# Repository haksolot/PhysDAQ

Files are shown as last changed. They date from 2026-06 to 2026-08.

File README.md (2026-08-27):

<p align="center">
  <picture>
    <source media="(prefers-color-scheme: dark)" srcset="assets/physdaq-dark.svg">
    PhysDAQ
  </picture>
</p>

<h1 align="center">PhysDAQ</h1>

<p align="center">
  <strong>Wearable multi-point pulse and motion recording, for research.</strong><br>
  Place the sensors, press record, get clean CSV. No wiring and no code.
</p>

<p align="center">
  
  
  
</p>

<p align="center">
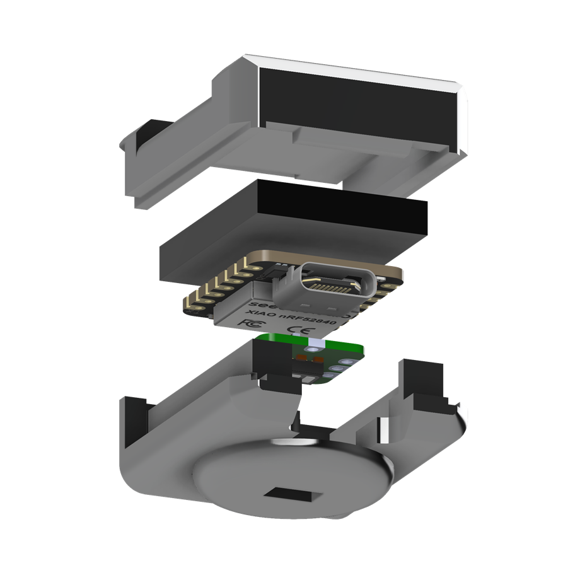
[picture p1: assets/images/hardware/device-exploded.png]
PhysDAQ sensor — exploded view
  
</p>
<p align="center"><sub><i>PhysDAQ sensor node — exploded view showing the XIAO nRF52840, MAX30102 pulse oximeter, LiPo battery and 3D-printed enclosure.</i></sub></p>

---

## Quick start

1. **Install the desktop app.** Download it from the
   [Releases page](https://github.com/haksolot/PhysDAQ/releases) — `.exe` for
   Windows, `.dmg` for Mac, `.AppImage` or `.deb` for Linux. The downloads are
   unsigned, so your system will warn you once; the
   [User Guide](docs/user-guide.md#installing-the-app) says what to click.
2. **Connect a sensor.** Plug it into a USB port, or pair it over Bluetooth from
   the app. The app finds it either way — nothing to configure.
3. **Name your session and press Record.** Every connected sensor is recorded at
   once, and you get one spreadsheet-ready CSV file per sensor in
   `Documents/PhysDAQ_Sessions/`.

Step by step, including where to place a sensor on the body and how to read the
live view: **[User Guide](docs/user-guide.md)**.

---

## Overview

<table>
<tr>
<td width="50%" valign="top">

### Hardware

A compact, battery-powered sensor node that clips to the body. Each unit combines a 6-axis IMU and a clinical-grade pulse oximeter in a 3D-printed enclosure.

<p align="center">
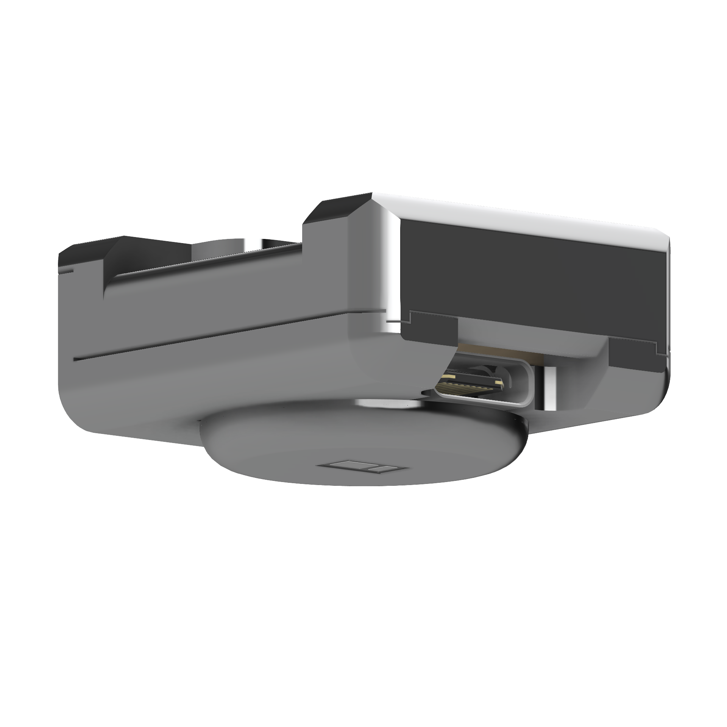
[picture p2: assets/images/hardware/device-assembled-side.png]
Assembled PhysDAQ sensor
  
</p>

</td>
<td width="50%" valign="top">

### Desktop App

A cross-platform acquisition interface that discovers sensors over USB or BLE, displays live signals, and exports timestamped CSVs.

<p align="center">
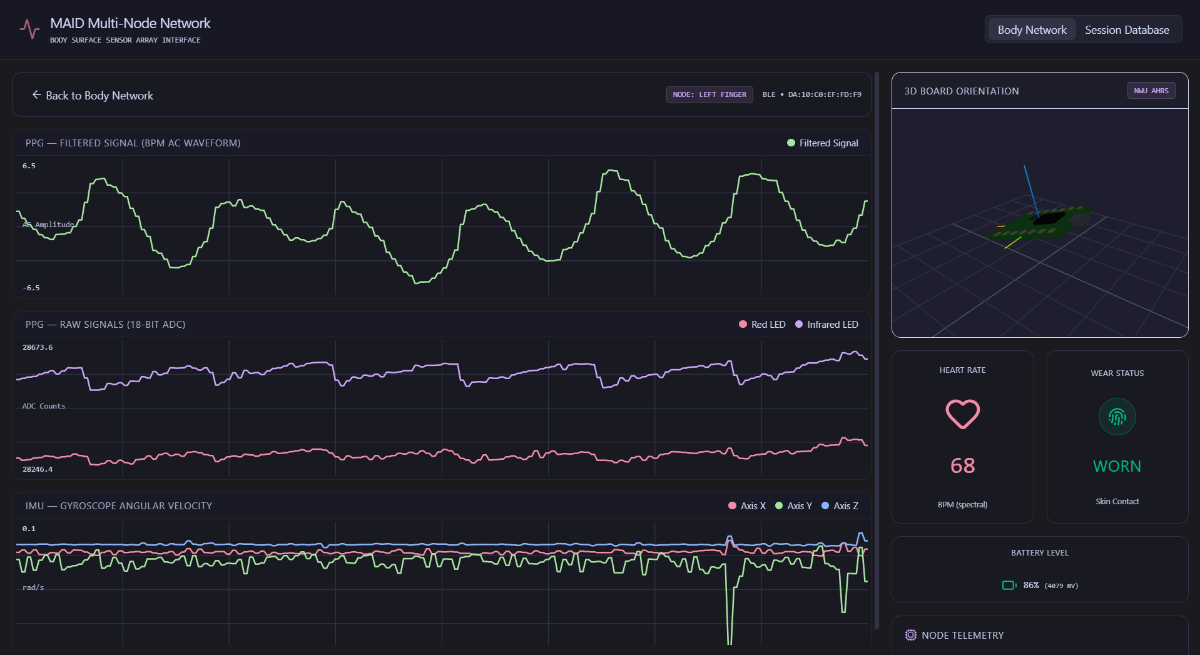
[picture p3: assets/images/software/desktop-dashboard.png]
PhysDAQ desktop dashboard
  
</p>

</td>
</tr>
</table>

---

## What you get

- **Pulse and motion together**, 100 times per second: the raw red and infrared
  light signals a pulse oximeter measures, plus 6-axis movement (acceleration
  and rotation).
- **Several sensors at once**, each pinned to a spot on an on-screen body map,
  all sharing one session clock.
- **Live plots and a 3D orientation view** while you record, so you can see a bad
  placement immediately instead of after the session.
- **Plain CSV files** — one per sensor, openable in Excel, R, MATLAB or pandas.
  Columns are documented, nothing is proprietary.
- **An offline analysis pipeline** for heart rate, heart-rate variability (RMSSD),
  blood-oxygen estimation and motion cancellation. See
  [Analysis Pipeline](docs/analysis.md) — note the CSV format caveat there.

---

## What you need

<p align="center">
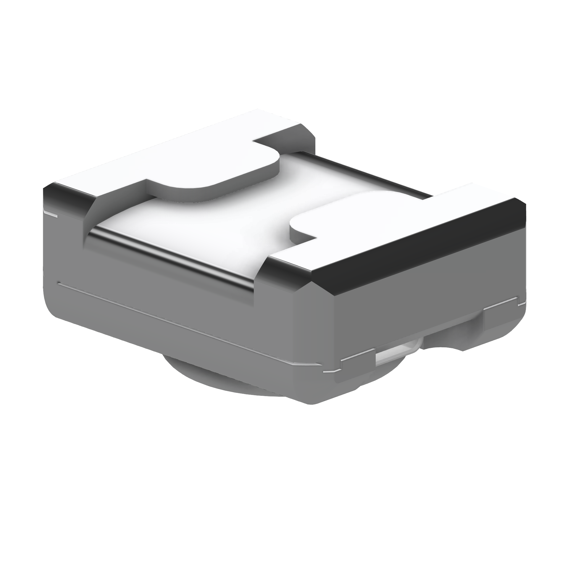
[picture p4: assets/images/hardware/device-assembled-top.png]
PhysDAQ sensor — top view
  
</p>

| Component | Specification |
| --- | --- |
| Sensor board | Seeed Studio XIAO nRF52840 Sense (motion sensor built in) |
| Pulse sensor | Maxim MAXREFDES117# (MAX30102), connected over I2C |
| Recording rate | 100 Hz, red + infrared, 18-bit |
| Connection | USB cable, or Bluetooth Low Energy |
| Power | Single-cell LiPo battery |
| Sleep current  | ~0.4 µA between sessions, wake-on-motion |

Full parts list, pin map and register configuration: **[Hardware Reference](docs/hardware.md)**.  
Enclosure CAD (STEP) and printing instructions: **[Enclosure](hardware/enclosure/README.md)**.

---

## Documentation

| If you want to | Read |
| --- | --- |
| Set up a sensor and record a session | [User Guide](docs/user-guide.md) |
| Build a sensor from parts | [Hardware Reference](docs/hardware.md) |
| Print the case | [Enclosure](hardware/enclosure/README.md) |
| Understand the recorded data format  | [Data Contracts](docs/protocol.md) |
| Process recordings offline | [Analysis Pipeline](docs/analysis.md) |
| Set up a development machine | [Development Guide](docs/development.md)  |
| Modify the firmware | [Firmware Reference](docs/firmware.md) |
| Modify the desktop app | [Desktop App](docs/desktop-app.md) |
| See what is planned | [Roadmap](docs/roadmap.md) |

---

## Status

Active research development at **BCIT** (Vancouver, BC). The firmware, the
acquisition bridge and the desktop app work end to end; see the
[Roadmap](docs/roadmap.md) for what is deliberately not built yet.

> **Research instrument — not a medical device.** Nothing here is validated for
> diagnosis, and no claim of clinical accuracy is made.

---

## Working on PhysDAQ

```bash
make setup           # one-time: fetch Zephyr v3.6.0 and modules (~2–3 GB)
make build && make flash
cd app && npm install && npm run dev
make help            # every other target
```

Toolchain setup, the Python environment, the build system and packaging:
**[Development Guide](docs/development.md)**.

---

## Licence

[MIT](LICENSE).

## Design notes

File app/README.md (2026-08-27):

# PhysDAQ Desktop App

Electron + React front-end for the PhysDAQ wearable. It does not talk to the
hardware itself — it spawns **`scripts/bridge.py`** (the *sidecar*) as a child
process, one per connected sensor, and reads JSON lines from its stdout.

```mermaid
flowchart LR
  MAIN["Electron main<br/>src/main/sidecar.ts"]
  BR["bridge (Python)<br/>numpy · scipy<br/>bleak · imufusion"]
  DEV(["XIAO nRF52840"])
  MAIN -- "spawn · stdin commands" --> BR
  BR -- "stdout JSON · stderr logs" --> MAIN
  BR <-- "serial / BLE" --> DEV
```

## Quick reference

```bash
npm install
npm run dev         # dev server with HMR (uses the repo's .venv for the bridge)
npm run typecheck
npm run build:win   # or build:mac / build:linux — builds the sidecar too
```

The dev build needs the repo's Python venv; see the setup steps in
[../docs/development.md](../docs/development.md).

## Full documentation

| | |
|---|---|
| Architecture, IPC surface, UI internals | [../docs/desktop-app.md](../docs/desktop-app.md) |
| Setup, build chain, packaging, troubleshooting | [../docs/development.md](../docs/development.md) |
| Bridge JSON and session CSV formats | [../docs/protocol.md](../docs/protocol.md) |
| Using the app | [../docs/user-guide.md](../docs/user-guide.md) |

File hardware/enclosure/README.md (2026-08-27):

# PhysDAQ Enclosure

3D-printable case for a PhysDAQ sensor node.

<p align="center">
  PhysDAQ sensor — exploded view
</p>

> **Status: a first design is filed, in STEP only.** The case and lid are
> modelled — [`models/physdaq-case-v1.step`](models/physdaq-case-v1.step) and
> [`models/physdaq-lid-v1.step`](models/physdaq-lid-v1.step) — but neither has
> an editable source (`.f3d`) or a printable mesh (`.stl`) committed alongside
> it, so the convention below is only half satisfied. Slice the STEP directly,
> or import it to reproduce a source.
>
> The constraints in this document remain the specification any design has to
> satisfy. See [roadmap.md](../../docs/roadmap.md).

This document covers the **single-PPG node**. The hub is a larger board build
with a different pin map and a microSD card, and has no enclosure design.

---

## What has to fit inside

| Component | Approximate footprint | Constraints |
|---|---|---|
| XIAO nRF52840 Sense | 21 × 17.5 × 3.5 mm | USB-C port and RST button must remain accessible |
| MAXREFDES117# | ~19 mm circular module | Optical window must reach the skin |
| LiPo cell | designer's choice | Soldered to the XIAO's BAT pads on the underside |
| Wiring | 5 conductors | 3V3, GND, SDA (D4), SCL (D5), INT (D1) |

Pin assignments and electrical details: [../../docs/hardware.md](../../docs/hardware.md).

---

## Design requirements

**Hard requirements** — the device does not work without these:

1. **Optical window flush with the skin.** The MAX30102's LEDs and photodiode
   must contact the skin directly, with no air gap and no material in the optical
   path. Either leave an open aperture or use an optically clear window; opaque
   or diffusing plastic over the sensor kills the signal.
2. **Optical isolation.** Light from the LEDs must not reach the photodiode
   except through tissue. A raised lip or an opaque baffle between emitter and
   detector prevents the direct crosstalk that flattens the PPG waveform.
3. **RST button accessible.** Flashing requires a **double-tap of RST**. A recess
   reachable with a fingernail or a small pin is enough; a fully buried button
   means disassembly for every firmware update.
4. **USB-C accessible.** Used for charging, flashing and full-rate 100 Hz
   acquisition. Full-rate capture is USB-only, so this is not just a
   charging port.
5. **Steady, light contact pressure.** Strap or clip geometry should hold the
   optical window against the skin without restricting perfusion — too tight and
   the pulse disappears.

**Should have:**

6. Antenna clearance — keep metal and dense infill away from the XIAO's PCB
   antenna edge.
7. Strain relief where the sensor wiring leaves the board.
8. Ventilation or thermal margin around the LEDs during long recordings.
9. Serviceable battery access, if the cell is not permanently bonded.

---

## Suggested print settings

Starting point, not gospel — tune to your printer.

| Setting | Value | Why |
|---|---|---|
| Material | PETG or ABS/ASA | Tolerates body heat and skin contact better than PLA, which creeps under sustained warmth |
| Layer height | 0.12–0.16 mm | Fine enough for the port and button cutouts |
| Walls | 3+ | Small parts need shell strength, not infill |
| Infill | 20–30 % | Little benefit above this at this size |
| Supports | Only for the USB/RST cutouts | Design to avoid them where possible |
| Tolerance | ~0.2 mm clearance on board pockets | Adjust to your printer's first-layer squish |

For skin-contact surfaces, prefer a material you are comfortable putting against
someone's arm for an hour. If the enclosure will be reused across participants,
consider a flexible (TPU) skin-side gasket that can be cleaned or replaced
separately.

---

## File conventions

Put design files in `models/`:

```
models/
  physdaq-case-v1.f3d       source (Fusion 360 — editable master)
  physdaq-case-v1.step      neutral CAD interchange
  physdaq-case-v1-top.stl   printable mesh
  physdaq-case-v1-base.stl
```

Rules:

- **Always commit the editable source**, not just meshes. An STL alone cannot be
  meaningfully revised.
- Also commit a **STEP** export — it survives the source tool going away or
  changing licence.
- One `vN` per revision that has been printed and tested. Do not overwrite a
  version that someone may have printed; bump it.
- Note the version and any print notes in this file's changelog below.

CAD extensions are marked `binary` in the repo's `.gitattributes`, so line-ending
normalisation will not corrupt them. Meshes are large — keep an eye on repo size,
and prefer regenerating STLs from source over committing many variants.

---

## Changelog

**v1** — first design, filed as `models/physdaq-case-v1.step` and
`models/physdaq-lid-v1.step`. STEP only: no editable source and no printable
mesh committed. The renders in the repository [README](../../README.md) are
taken from it. Print notes: none recorded — this revision has not been
verified against the design requirements above on a printed part.

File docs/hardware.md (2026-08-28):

# Hardware Reference

Everything about the physical PhysDAQ node: what it is made of, how it is wired,
how each sensor is configured, and how it manages power.

This document covers the **single-PPG node**. The hub — two PPG sensors behind an
I2C mux, plus a microSD card on SPI — is a different board build with a different
pin map; see [firmware-hub.md](firmware-hub.md#wiring).

---

## Bill of materials

| Component | Part | Role |
|---|---|---|
| MCU board | Seeed Studio XIAO nRF52840 Sense | Main controller, BLE radio, onboard IMU |
| PPG module | Maxim MAXREFDES117# | MAX30102 pulse-oximetry front end |
| Battery | Single-cell LiPo (3.7 V nominal) | Untethered operation |

The MAXREFDES117# is wired to the XIAO connector with four conductors
(3V3, GND, SDA, SCL) plus one interrupt line.

---

## XIAO nRF52840 Sense — connector pin map

Verified against `seeed_xiao_connector.dtsi` and `xiao_ble-pinctrl.dtsi` in the
vendored Zephyr tree.

| Connector | nRF52840 pin | Alternate function | Connected to |
|---|---|---|---|
| D0 | P0.02 | GPIO | *unused* |
| D1 | P0.03 | GPIO | MAX30102 INT |
| D2 | P0.28 | GPIO | — |
| D3 | P0.29 | GPIO / ADC | — |
| D4 | **P0.04** | I2C1 SDA | MAX30102 SDA |
| D5 | **P0.05** | I2C1 SCL | MAX30102 SCL |
| D6 | P1.11 | UART TX | — |
| D7 | P1.12 | UART RX | — |
| 3V3 | — | Power | MAX30102 VCC |
| GND | — | Ground | MAX30102 GND |

> ⚠️ **Common mistake:** D4 = P0.04 and D5 = P0.05 — **not** P0.26/P0.27.
> P0.26 is the onboard red LED, which does not conflict with I2C1. Wiring the
> PPG module to P0.26/P0.27 is the single most common bring-up error on this
> board.

**Onboard LEDs** (already declared in `xiao_ble_common.dtsi`, no overlay needed):

| Alias | Pin | Colour |
|---|-----|---|
| led0 | P0.26 | Red |
| led1 | P0.30 | Green |
| led2 | P0.06 | Blue |

**Other pins used by the firmware:**

| Pin | Purpose |
|-----|---|
| P0.31 / AIN7 | VBAT sense through the onboard 1 MΩ / 510 kΩ divider |
| P0.14 | Divider enable (active low) — gated so the divider does not drain the cell |
| P0.11 | LSM6DS3TR-C INT1 — wake-on-motion source out of deep sleep |
| P1.08 | LSM6DS3TR_C_EN regulator (board-managed) |

---

## I2C bus layout

| Bus | Compatible | Pins | Device | Address |
|-----|---|---|---|---|
| i2c0 | `nordic,nrf-twim` | SDA=P0.07, SCL=P0.27 | LSM6DS3TR-C (IMU, onboard) | 0x6A |
| i2c1 | `nordic,nrf-twi` | SDA=D4/P0.04, SCL=D5/P0.05 | MAX30102 (PPG, external) | 0x57 |

`i2c0` is wired internally on the board and is not exposed on the connector.
`i2c1` is the external connector bus; its pin control is defined in
`xiao_ble-pinctrl.dtsi`. The MAX30102 node is added in
`firmware/boards/xiao_ble_sense.overlay` at standard bit rate (100 kHz).

### Wiring

Five conductors leave the XIAO for the PPG module. Everything else in this
picture is already on the board.

```mermaid
flowchart LR
  subgraph XIAO["XIAO nRF52840 Sense"]
    direction TB
    I2C1["i2c1 · D4 P0.04 SDA<br/>D5 P0.05 SCL<br/>100 kHz"]
    INT["D1 · P0.03<br/>GPIO in, pull-up<br/>falling edge"]
    RAIL["3V3 · GND"]
    I2C0["i2c0 · P0.07 / P0.27<br/>internal, 400 kHz"]
    ADC["P0.31 / AIN7<br/>gated by P0.14"]
  end

  PPG["MAXREFDES117#<br/>MAX30102 @ 0x57"]
  IMU["LSM6DS3TR-C @ 0x6A<br/>onboard"]
  BAT["LiPo cell<br/>1 MΩ / 510 kΩ divider"]

  I2C1 --> PPG
  RAIL --> PPG
  PPG -. "PPG_RDY, active low" .-> INT
  I2C0 --> IMU
  IMU -. "INT1 · P0.11<br/>wake-on-motion" .-> XIAO
  BAT --> ADC
```

> ⚠️ **D4 = P0.04, D5 = P0.05.** Not P0.26/P0.27 — P0.26 is the onboard red LED.
> This is the single most common bring-up error on this board.

The PPG module has no enable pin, so its rail is always live; low power is
`MODE_CONFIG = 0x80` (SHDN) over I2C. D0 / P0.02 is consequently unused on the
node.

---

## MAX30102 PPG front end (MAXREFDES117#)

### Power control

The MAXREFDES117# has **no accessible EN/SHDN pin** — confirmed both by hardware
debugging and by Maxim's documentation. The MAX30102 is powered whenever VIN is
connected; there is no software power gating on this module. D0/P0.02 is **not
used** — do not add an `en-gpios` property to the DTS or drive one in firmware.

Low-power operation is achieved instead by putting the chip into its own SHDN
mode over I2C (see [Power management](#power-management) below).

### Interrupt line

- Active **LOW**, open-drain — requires a pull-up, configured via `GPIO_PULL_UP`
  in the overlay.
- Wired to D1 / P0.03.
- Fires on `PPG_RDY`: one interrupt per new FIFO sample, i.e. 100 Hz.

### Register configuration

| Parameter | Value | Register |
|---|---|---|
| Mode | SpO2 (Red + IR) | `MODE_CFG` = 0x03 |
| Sample rate | 100 Hz | `SPO2_CFG` = 0x67 |
| ADC resolution | 18-bit | `SPO2_CFG` |
| ADC range | 3 (full scale) | `SPO2_CFG` |
| LED pulse width | 411 µs | `SPO2_CFG` |
| LED amplitude (Red + IR) | 0x1F ≈ 6.2 mA | `LED1_PA`, `LED2_PA` |
| FIFO rollover | **enabled** | `FIFO_CFG` = 0x10 |
| Part ID (register 0xFF) | 0x15 | read-only, checked at init |

> **FIFO rollover must stay enabled.** With rollover off, the 32-deep FIFO wedges
> permanently the first time the host falls behind, and acquisition never
> recovers.

**Driver:** custom register-level I2C driver in `firmware/src/max30102.c`. There
is no Zephyr native MAX30102 driver in use. The DTS binding lives at
`firmware/dts/bindings/sensor/maxim,max30102.yaml`.

---

## IMU — LSM6DS3TR-C (onboard)

- Bound in Zephyr DTS as `compatible = "st,lsm6dsl"` (compatible superset).
- Located at `i2c0 @ 0x6A`, powered through a `regulator-fixed` node
  (`LSM6DS3TR_C_EN` on P1.08).
- Driver: Zephyr built-in, `CONFIG_LSM6DSL=y`.
- Configured at **104 Hz ODR** for both accelerometer and gyroscope.
- Wrapper: `firmware/src/imu.c` — `imu_init()`, `imu_fetch_sample()`,
  `imu_print_sample()`.

**Units** (Zephyr sensor API): accelerometer in **m/s²**, gyroscope in **rad/s**
— *not* degrees per second. This trips people up when comparing against
datasheets or other IMU libraries. The bridge converts to g and deg/s internally
before feeding the AHRS filter.

There is **no magnetometer** on this board. Absolute heading is therefore
unavailable and yaw drifts over time; see [docs/analysis.md](analysis.md) for how
the software mitigates this.

---

## Battery sensing

VBAT is measured through the board's onboard resistor divider (1 MΩ / 510 kΩ)
into AIN7 / P0.31. The divider is gated by P0.14 (active low) so it does not
continuously drain the cell.

- Sampled every 5 s (`battery_poll()` is internally rate-limited).
- State of charge from an 11-point single-cell LiPo discharge curve with linear
  interpolation between points: **4200 mV = 100 %**, **3300 mV = 0 %**.
- Reported on both transports as a plain line:

```
Battery: 71% (3940 mV)
```

Source: `firmware/src/battery.c`. The overlay declares the `battery_divider`
`voltage-divider` node and the ADC channel (gain 1/6, internal reference,
12-bit, `NRF_SAADC_AIN7`).

---

## Power management

The firmware enters **nRF System Off** (~0.4 µA) after a configurable period of
inactivity. "Inactivity" means **all** of: no gyroscope motion, no IR contact,
and **no host link** (neither a BLE connection nor a USB port held open, seen as
CDC DTR) — so wearing the device while sitting perfectly still (resting,
sleeping) does *not* trigger sleep, and neither does a node sitting on the bench
with the desktop app connected to it, by radio or by cable. Only setting it
down, unworn and unconnected, does.

```mermaid
stateDiagram-v2
  direction LR
  [*] --> Awake
  Awake --> Awake: motion, or skin contact,<br/>or BLE / USB host link — timer resets
  Awake --> Sleeping: none of them<br/>for IDLE_TIMEOUT_SEC
  Sleeping --> Awake: IMU INT1 asserts (~125 mg)<br/>GPIO DETECT → full CPU reset
  note right of Sleeping
    System Off, ~0.4 µA
    No state survives.
    USB CDC port disappears.
  end note
```

### Contact detection

`contact_is_skin()` in `firmware/src/contact.c` is a DC-level check on the IR
channel: an exponential moving average `dc += 0.05 × (ir − dc)` (~0.8 Hz corner,
~200 ms response) compared against `CONTACT_DC_MIN = 5000`. Open air reads
roughly 100–300 counts; something resting on the sensor reads 29 000+.

The threshold is deliberately the same number as `CONTACT_IR_MIN` in
`scripts/bridge.py` and `analysis/pipeline.py`, so host and device agree on what
"worn" means.

> An earlier version additionally required a validated heartbeat (consecutive
> peak intervals in a plausible cardiac range) to reject inert reflective
> surfaces. The embedded peak detector never found one reliably on real hardware,
> so it was reverted to the DC-only check already proven on the host side.
> **Known limitation:** a non-skin reflective surface at the right distance still
> registers as contact.

### Sleep sequence

1. No gyro motion above 0.1 rad/s, no IR contact, **and** no BLE link, all for
   `CONFIG_PHYSDAQ_IDLE_TIMEOUT_SEC` seconds.
2. BLE is stopped (`ble_stop()`) — the controller must be idle before System Off.
3. MAX30102 is put in SHDN mode (LEDs off, ~0.7 µA, I2C still alive).
4. LSM6DS3TR-C is reconfigured for accel-only 26 Hz wake-up detection on INT1
   (P0.11), threshold ~125 mg.
5. The nRF enters System Off via `nrf_power_system_off()` — all GPIO go
   high-impedance.

### Wake sequence

- Physical movement → IMU asserts INT1 high → nRF GPIO sense DETECT → **full CPU
  reset**.
- The firmware boots from scratch; sensors re-initialise normally. There is no
  state preserved across sleep.
- The USB CDC serial port disappears during sleep and reappears on wake — restart
  `make term` (or reconnect in the desktop app) after waking a node.

### Configuring the timeout

Edit `firmware/prj.conf`:

```
CONFIG_PHYSDAQ_IDLE_TIMEOUT_SEC=10   # then: make rebuild && make flash
```

Valid range is 5–300 s (enforced in `firmware/Kconfig`). No source changes are
needed. Because this is a Kconfig symbol, use `make rebuild` rather than
`make build` if you have just renamed or added symbols.

While awake and idle, a status line goes out every 5 s — to the USB console
*and* over BLE — so you can watch the countdown:

```
Power: idle 4s/10s | skin: yes (dc=29050) | ble: no | peak ~12mrad/s (thresh 100mrad/s)
```

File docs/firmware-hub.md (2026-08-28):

# Firmware — Hub node (`firmware-hub/`)

Dual-PPG acquisition node that logs to microSD. Copied from
[`firmware/`](../firmware/) (the single-PPG node) and adapted; the MAX30102
register sequences are carried over verbatim.

This is the **prototype track** — off-the-shelf modules on breadboard. The
custom PCB track (MAX86178 / ICM-20948 / BQ25120A) is out of scope here.

Phase 1 (this document) acquires two local PPG streams and writes them to the
card. Phase 2 turns the same device into a hub that also ingests remote
single-PPG nodes over the radio — designed for, not implemented.

---

## Hardware

| Part | Detail |
|---|---|
| MCU | Seeed XIAO nRF52840 Sense — Zephyr board `xiao_ble_sense` |
| IMU | onboard LSM6DS3TR-C @ 0x6A, internal I2C bus |
| Mux | PCA9546A @ 0x70 (A0/A1/A2 to GND) |
| PPG | 2× MAXREFDES117# (MAX30102), both strapped to 0x57 |
| Storage | Adafruit microSD BFF (5683), discrete jumpers, SPI |

### Pin map

Sensors are named `ppg0` and `ppg1` throughout, matching the DeviceTree
labels in `firmware-hub/boards/xiao_ble_sense.overlay` and the `PPG_SRC_LOCAL_0`
/ `PPG_SRC_LOCAL_1` source IDs written into every record. Avoid "#1 / #2" — the
off-by-one against the zero-based source IDs is how the INT pairing below got
documented backwards once already.

| XIAO | nRF52840 | Function |
|---|---|---|
| D0 | P0.02 | INT, `ppg1` (mux channel 2) |
| D1 | P0.03 | INT, `ppg0` (mux channel 1) |
| D2 | P0.28 | PCA9546A RESET (active low) |
| D3 | P0.29 | reserved — future load switch on the PPG supply rail |
| D4 | P0.04 | I2C SDA (upstream) |
| D5 | P0.05 | I2C SCL (upstream) |
| D6 | P1.11 | SPI CS, microSD |
| D7 | P1.12 | unused |
| D8 | P1.13 | SPI SCK |
| D9 | P1.14 | SPI MISO |
| D10 | P1.15 | SPI MOSI |

### Bus topology

The upstream I2C bus is **`i2c1` (D4/D5) at 400 kHz**, with the PCA9546A at
0x70. `ppg0` is on mux **channel index 1**, `ppg1` on **channel index 2**;
indices 0 and 3 are unused and unpopulated.

> **Channel indices are not the breakout's pad labels.** The hand-off report
> says channels 2 and 3 because that is what the silk screen reads, but this
> breakout numbers its pads 1-4 while the part numbers its channels 0-3. The
> pads marked `SD2/SC2` and `SD3/SC3` are indices 1 and 2. Measured, not
> assumed — the boot self-test walks all four channels and prints which ones
> answer at 0x57. If you swap the breakout, re-run it and believe its output
> over the labels.

> **`i2c0` is the internal IMU bus, `i2c1` is the exposed one.** The hand-off
> report has these the other way round. Verified against the board files:
> `xiao_ble-pinctrl.dtsi` maps `i2c0` to P0.07/P0.27 — where `xiao_ble_sense.dts`
> places the LSM6DS3TR-C — and `i2c1` to P0.04/P0.05, which
> `seeed_xiao_connector.dtsi` aliases as `xiao_i2c`. The physical pins in the
> report are right; only the peripheral labels were swapped.

The two **INT lines bypass the mux** and land on plain GPIOs. That is what lets
a sample-ready event be timestamped the instant it fires, independently of which
mux channel happens to be selected. Do not route them through the mux.

### Wiring

Both PPG modules answer at 0x57 and the address is not strappable — that is the
only reason the mux exists. Note that each sensor's INT line and its mux channel
are **independent facts**: the wire pairing was measured by the boot self-test,
not inferred from the channel number, and pairing them wrong still acquires
cleanly with every timestamp attributed to the wrong body site.

```mermaid
flowchart LR
  subgraph XIAO["XIAO nRF52840 Sense"]
    direction TB
    I2C1["i2c1 · D4 P0.04 SDA<br/>D5 P0.05 SCL<br/>400 kHz"]
    RST["D2 · P0.28<br/>RESET, active low"]
    INT0["D1 · P0.03<br/>GPIO in, pull-up"]
    INT1["D0 · P0.02<br/>GPIO in, pull-up"]
    SPI["spi2 · D6 P1.11 CS<br/>D8 P1.13 SCK<br/>D9 P1.14 MISO<br/>D10 P1.15 MOSI<br/>4 MHz"]
    I2C0["i2c0 · P0.07 / P0.27<br/>internal, 400 kHz"]
  end

  PU["4.7 kΩ pull-ups<br/>to 3V3"]
  MUX["PCA9546A @ 0x70"]
  PPG0["ppg0 · MAX30102 @ 0x57"]
  PPG1["ppg1 · MAX30102 @ 0x57"]
  SD["microSD BFF 5683"]
  IMU["LSM6DS3TR-C @ 0x6A"]

  I2C1 --- PU
  PU --> MUX
  RST --> MUX
  MUX -- "channel 1<br/>pads silkscreened 2" --> PPG0
  MUX -- "channel 2<br/>pads silkscreened 3" --> PPG1
  PPG0 -. "INT, bypasses mux" .-> INT0
  PPG1 -. "INT, bypasses mux" .-> INT1
  SPI --> SD
  I2C0 --> IMU
```

3V3 and GND run from the XIAO to the mux, both PPG modules and the microSD
breakout. The PPG modules have no enable pin — low power is `MODE_CONFIG = 0x80`
(SHDN) over I2C, so the supply rail is always live. D3 / P0.29 is reserved for a
future load switch on that rail and has no DeviceTree node today.

---

## Invariants — do not break these

- **`uart0` must stay disabled.** It claims P1.11 in the board devicetree, and
  P1.11 is now the SD chip select. Two peripherals on one pad is a silent
  failure. The console is USB CDC ACM, so nothing is lost.
- **`spi2` is overridden to `nordic,nrf-spim`.** The board declares plain
  `nordic,nrf-spi`, which services a 512-byte block one byte-interrupt at a
  time and would contend with the two PPG interrupts. EasyDMA keeps the
  acquisition ISRs clean.
- **`CONFIG_I2C_TCA954X_CHANNEL_INIT_PRIO` must exceed `..._ROOT_INIT_PRIO`.**
  Both default to `I2C_INIT_PRIORITY` in Zephyr 3.6 while the driver carries a
  `BUILD_ASSERT` demanding they differ — the upstream defaults do not compile.
  Set to 51 and 50 in `prj.conf`.
- **The MAX30102 FIFO rollover stays enabled** (`FIFO_CFG = 0x10`), same as the
  single-PPG node. With it off the FIFO wedges permanently the first time the
  host falls behind.
- **Timestamps are captured in the GPIO ISR**, never after the mux switch or
  the FIFO read. See *Timing* below.
- **Deep sleep is off** (`CONFIG_PHYSDAQ_DEEP_SLEEP=n`). A hub records
  unattended and is routinely stationary and unworn — exactly the state the
  idle timer reads as "put down".
- **`storage_init()` must run before `ppg_init()`.** It anchors the session
  clock, and the acquisition threads read that epoch once at start-up.
- **The file system has exactly one owner: the storage thread.** Every command
  that touches the card goes through `storage_*()`, which posts a request and
  blocks. FATFS is not reentrant across a volume, and a second thread calling
  `fs_*` would race the writer holding the session file open.
- **Nothing on either stream may start with `PPG` except the sample line.**
  `bridge.py` discards unmatched lines beginning with those three characters, so
  a status line or command reply prefixed that way would vanish silently. This
  is why they read `Hub:`, `SD`, `REC`, `SAT`, `ID`.

---

## Architecture

| File | Responsibility |
|---|---|
| `main.c` | Init order, supervisor loop, IMU, BLE line formatting, status line, periodic diagnostics |
| `ppg.c/.h` | One acquisition thread per sensor; ISR timestamping, FIFO drain, record enqueue |
| `storage.c/.h` | The only file-system owner: session files, block packing, `fs_sync`, maintenance requests |
| `command.c/.h` | Host command grammar, reply formatting, base64 download |
| `satellites.c/.h` | NVS-backed roster of up to 8 remote nodes — configuration only |
| `selftest.c/.h` | Boot and periodic bus diagnostics — see below |
| `max30102.c/.h` | Register-level driver, shared by both sensor threads |
| `ble.c/.h`, `power.c/.h`, `battery.c/.h`, `watchdog.c/.h`, `imu.c/.h`, `led.c/.h` | As on the single-PPG node, with the divergences noted here |
| `version.h` | `PHYSDAQ_FW_STRING`, shared by the `ID` line and `hdr.fw_version` |

Five threads plus the supervisor:

| Thread | Prio | Stack | Role |
|---|---|---|---|
| `ppg0`, `ppg1` | 4 | 1536 | one per sensor: wait on INT, drain FIFO, timestamp, enqueue |
| `storage` | 7 | 4096 | dequeue, pack into 512 B blocks, write, periodic `fs_sync()`, service maintenance requests |
| `cmdproc` | 8 | 3072 | parse host commands, reply |
| `cmdconsole` | 9 | 1024 | read the USB console, feed `cmdproc` |
| `main` | — | 2048 | watchdog, IMU, BLE stream, status lines; supervisor turns over every 40 ms |

Acquisition outranks storage deliberately: an SD card doing internal
wear-levelling can block a write for tens of milliseconds, and that must never
delay a FIFO drain. The `k_msgq` between them holds 512 records (8 kB), about
2.5 s of headroom at 200 records/s. `records_dropped` in the status line is the
check that it was enough — it should be zero, always.

The command threads sit *below* storage, which is the same reasoning one rung
down: nothing a human triggers is time-critical, and a queued command must never
be the reason a card write is late.

Bus arbitration is handled entirely by Zephyr's `tca954x` driver, which
serialises (channel select + transfer) under its own mutex. **Do not add a
second layer of locking.**

Two planes run through those threads, and they meet only at the storage thread:

```mermaid
flowchart TB
  INT0(["ppg0 INT<br/>D1 · P0.03"]) --> T0["ppg0 · prio 4<br/>timestamp in ISR, drain FIFO"]
  INT1(["ppg1 INT<br/>D0 · P0.02"]) --> T1["ppg1 · prio 4<br/>timestamp in ISR, drain FIFO"]
  T0 --> Q["k_msgq<br/>512 records · 8 kB · ~2.5 s"]
  T1 --> Q
  Q --> ST["storage · prio 7<br/>pack 512 B blocks, periodic fs_sync"]
  ST --> FS[("/SD:/SESSNNNN.BIN")]

  CON["cmdconsole · prio 9<br/>USB console"] --> CQ
  BLERX["BLE on_rx_write<br/>NUS RX characteristic"] --> CQ["cmd_q · 4 lines"]
  CQ --> CP["cmdproc · prio 8<br/>parse, reply"]
  CP -- "storage_req, blocks<br/>depth 1" --> RQ["request_q"]
  RQ --> ST

  MAIN["main · supervisor 40 ms<br/>watchdog, IMU, status"] -- "one line per sample,<br/>rate-limited to ~25 Hz" --> BLETX["BLE TX"]
  T0 -.-> MAIN
  T1 -.-> MAIN
```

**Only the storage thread touches the file system.** Commands post a request and
block on the reply — FATFS is not reentrant across a volume, and the storage
thread holds the session file open. Enqueueing times out after 2 s, completion
after 10 s.

### Bus self-test

`selftest.c` runs at boot and then every 10 s **while not acquiring** — it drives
the mux registers directly, behind the `tca954x` driver's back, which is only
safe when no acquisition thread is mid-transfer. Never relax that gate.

What it establishes, in order:

1. **Idle SDA/SCL levels**, read straight off the pads. Both low means no
   pull-ups (or a short); this is the one failure the address probe cannot
   distinguish from an empty bus.
2. **RESET pulse and pad readback** on D2. It cannot prove the mux saw the
   pulse — only that the MCU drove it.
3. **A full 0x08–0x77 scan**, by 1-byte read rather than a zero-length write:
   some parts NACK the address-only form even when present.
4. **A four-channel walk**, confirming 0x57 both *appears* on the enabled
   channel and *disappears* on the others. Appearing alone would not rule out
   a stuck-open mux.
5. **The INT ↔ channel pairing**, by quiescing both sensors, enabling one, and
   watching which line falls. This is the only way to learn the pairing — it is
   wiring, not addressing, and getting it wrong still produces clean data
   attributed to the wrong body site.

Believe its output over the breakout's silk screen.

### Failure handling

- **Per-sensor stall recovery.** If a sensor produces nothing for 1 s, its own
  thread re-runs init. One dead sensor cannot take the other down, and the
  session file stays open.
- **Watchdog scope changed** from the single-PPG firmware: it now guards the
  supervisor loop, not acquisition. Resetting the SoC over a wedged sensor
  would close the session file, which is worse than the wedge. Otherwise the
  configuration is the node's: `wdt0`, 8 s, `WDT_FLAG_RESET_SOC`,
  `WDT_OPT_PAUSE_HALTED_BY_DBG`, and deliberately **not**
  `WDT_OPT_PAUSE_IN_SLEEP`.
- **Fatal errors reboot, and are reported.** `crashlog.c` overrides the fatal
  handler (noinit-RAM record + immediate reboot) exactly as on the node; the
  default halt left the hub silent for 8 s until the watchdog fired.
- **A missing card is not fatal.** Acquisition still runs and streams over BLE;
  the boot banner says `Storage: UNAVAILABLE` loudly.
- **Sleep closes the session file.** `power.c` calls `storage_close()` before
  System Off. Deep sleep is disabled on the hub today, so this is insurance for
  the day it is not.

---

## Timing

Single monotonic source for both sensors: **`k_uptime_ticks()`**, the 32768 Hz
RTC on nRF52 (`CONFIG_SYS_CLOCK_TICKS_PER_SEC = 32768` — that is the symbol
`k_uptime_ticks()` and `hdr.tick_hz` follow; `..._HW_CYCLES_PER_SEC` happens to
carry the same value and is not the one to override). Resolution
**30.5 µs**; 64-bit, so it never wraps.

30.5 µs is 0.3 % of a 10 ms sample period, comfortably below the MAX30102's own
sample jitter and its 411 µs LED pulse width. `k_cycle_get_32()` has the same
resolution but wraps every ~36 h, which is why it is not used.

Two correctness details that are easy to get wrong and invisible in testing:

1. **`isr_ticks` is read under `irq_lock()`.** It is a `uint64_t` written from
   interrupt context; a Cortex-M4 loads it as two 32-bit accesses, and an
   interrupt landing between them yields a value that never existed — off by
   2^32 ticks (~36 h) near a low-word rollover.
2. **The timestamp is paired with the FIFO write pointer under a seqlock-style
   retry.** Reading the pointers takes a few hundred microseconds; an interrupt
   landing inside that window advances the write pointer *after* the timestamp
   was taken, so the batch would contain one sample newer than the timestamp
   applied to it — dating the newest sample a full ODR period early.

### Batch back-dating

The FIFO is read in bulk, so the interrupt belongs to the **newest** entry.
Older entries are back-dated from the ODR, computed as a single 64-bit
multiply-then-divide so the rounding error stays under one tick across the
batch instead of compounding. Every back-dated record carries
`PPG_FLAG_BACKDATED`, so an offline reader can always tell a measured timestamp
from a derived one.

---

## File format

`/SD:/SESSNNNN.BIN` — one 512-byte header, then a stream of 16-byte records.
Little-endian throughout. Binary only; convert offline.

16 bytes means 32 records make exactly one 512-byte SD block, and the header
occupies one block on its own, so steady-state writes are block-aligned.

### Header (512 B)

| Offset | Type | Field |
|---|---|---|
| 0 | char[8] | `MAIDLOG1`, not NUL-terminated |
| 8 | u16 | `header_size` = 512 |
| 10 | u16 | `record_size` = 16 |
| 12 | u16 | `format_version` = 1 |
| 14 | u16 | `odr_hz`, per sensor |
| 16 | u32 | `session_id` — the NNNN in the filename |
| 20 | u32 | `tick_hz` = 32768 |
| 24 | u64 | `epoch_ticks` — absolute tick count at session open |
| 32 | u8 | `led_pa` — LED pulse amplitude register (0x1F ≈ 6.2 mA) |
| 33 | u8 | `spo2_cfg` — SPO2_CONFIG register (0x67 at 100 Hz) |
| 34 | u8 | `src_count` |
| 35 | u8 | reserved |
| 36 | u8[8] | `src_mux_ch[i]` = mux channel index for source i, `0xFF` if not local |
| 44 | u8[4] | `fw_version` — major, minor, patch, tweak |
| 48 | u8[464] | reserved |

Read `header_size` and seek by it. Do not assume `sizeof(struct)`.

### Record (16 B)

| Offset | Type | Field |
|---|---|---|
| 0 | u8 | `source_id` |
| 1 | u8 | `flags` |
| 2 | u16 | `seq` — per source, wraps at 65536 |
| 4 | u32 | `t_ticks` — ticks since `epoch_ticks` |
| 8 | u32 | `red` — raw 18-bit count, zero-extended |
| 12 | u32 | `ir` |

**Source IDs.** `0x00`–`0x0F` are sensors physically on this board. Which mux
channel each one sits on is recorded per-file in `src_mux_ch`, derived from the
devicetree rather than hardcoded — the mapping has already moved once and a
header that disagreed with the overlay would mislabel every recording made with
it. `0x10`+ is reserved for remote nodes ingested over the radio in Phase 2. The field is wide enough that node identification can be
assigned later without a format change.

**Flags.**

| Bit | Name | Meaning |
|---|---|---|
| 0 | `BACKDATED` | timestamp derived from the ODR, not an interrupt capture |
| 1 | `OVERFLOW` | the part dropped samples; there is a gap immediately before this record |
| 2 | `UNTIMED` | recovered on the poll-timeout path; treat the timestamp as approximate |

**Absolute time** of a record is `epoch_ticks + t_ticks`, in units of
`1/tick_hz` seconds. `t_ticks` is 32-bit at 32768 Hz, so a single session can
run ~36 h before it would wrap.

**Sample loss** is detectable two ways: a `seq` discontinuity (records dropped
between the sensor and the card) and the `OVERFLOW` flag (samples the sensor
itself discarded because the firmware fell behind).

### Durability

`fs_sync()` runs at least every `CONFIG_PHYSDAQ_SD_SYNC_INTERVAL_MS`
(default **1000 ms**), and any partially filled block is pushed out first. An
ungraceful power loss therefore costs **at most one second** — roughly 200
samples, 3.2 kB, at two sensors and 100 Hz.

> Not yet wired into the offline pipeline. `analysis/pipeline.py` reads the
> logger's CSV and knows nothing about this format; a reader has to be written.
> See [roadmap.md](roadmap.md).

---

## Configuration

| Symbol | Default | Notes |
|---|---|---|
| `PHYSDAQ_PPG_ODR_HZ` | 100 | 50 / 100 / 200 / 400 only. 100 is the validated rate; higher is unproven on this hardware |
| `PHYSDAQ_SD_SYNC_INTERVAL_MS` | 1000 | upper bound on data lost to a power cut |
| `PHYSDAQ_DEEP_SLEEP` | `n` | off on the hub — see Invariants |
| `PHYSDAQ_IDLE_TIMEOUT_SEC` | 10 | only acts when deep sleep is enabled |

`PHYSDAQ_PPG_ODR_HZ` accepts 50 / 100 / 200 / 400 only because it is compiled
into the MAX30102's `SPO2_CFG` sample-rate field: `0x60 | (SR << 2) | 0x03`, with
`SR` chosen by a lookup in `max30102.h` and an `#error` on anything else. A
`BUILD_ASSERT` pins the 100 Hz case to the validated `0x67`, so a change to the
derivation that silently altered the default fails the build.

Beyond the PhysDAQ symbols, `prj.conf` carries blocks the node does not need:
the `tca954x` mux driver (with the init priorities pinned in *Invariants*), the
SPI / SDHC / FATFS stack, `CONSOLE_SUBSYS` + `CONSOLE_GETCHAR` for the command
channel, `BASE64` for downloads, and NVS for the satellite roster.

> **Temporary:** the SD debug-logging block (`LOG_MODE_MINIMAL`,
> `SDHC_LOG_LEVEL_DBG`, `SD_LOG_LEVEL_DBG`) is still enabled, and is marked in
> `prj.conf` for removal once the card mounts reliably. It costs flash and
> console bandwidth; drop it when bring-up step 4 passes.

---

## Build

```bash
make hub          # incremental
make hub-rebuild  # pristine — after overlay or Kconfig changes
make hub-flash    # UF2 to the XIAO-SENSE bootloader drive
```

Builds into `build-hub/`, separate from the single-PPG firmware's `build/`, so
the two coexist. A Zephyr toolchain must be active — see
[development.md](development.md).

---

## BLE

The hub advertises the NUS service exactly like a single-PPG node, so the
service-UUID discovery filter is unchanged. It additionally puts a
manufacturer-specific AD field on the wire carrying the device class, and emits
an `ID` line on both transports — see [protocol.md](protocol.md) for both.

The per-sample line carries **both** sensors, and stays a superset of the
single-PPG format:

```
PPG red=… ir=… | PPG1 red=… ir=… | IMU ax=… ay=… az=… gx=… gy=… gz=…
```

One line, not two, and the `PPG red=` prefix is load-bearing: `bridge.py`
matches with `re.search`, so an un-updated bridge still parses sensor 0 out of
this line, whereas a *separate* line beginning `PPG1` would be silently dropped
(the parser discards any unmatched line starting with `PPG`). Keeping the pair
in one message also gives them a single arrival timestamp on the host.

A `Hub:` status line every 5 s carries the rest — per-sensor counts, overflow
and reinit counters, and storage statistics.

Still rate-limited to ~25 Hz. The link carries ~4 kB/s; the raw two-sensor
stream is several times that and would overflow the TX queue.

The transmit path is the node's, verbatim: `ble_send()` only queues, a dedicated
TX thread is the only caller of `bt_gatt_notify()` (which blocks with `K_FOREVER`
on buffer exhaustion — see [firmware.md](firmware.md#blec)), the controller runs
Data Length Extension, and the connection-parameter auto-update is off. The
`ID` line is followed by the same boot report (`Boot:` / `Crash:` / `Hang:`),
emitted from `command_send_identity()`; `crashlog.c` owns the reset cause here.

---

## Bring-up status

Per the hand-off report's checklist, against the physical prototype.

| # | Step | Status |
|---|---|---|
| 1 | I2C scan — only 0x70 answers | **pass** |
| 2 | Mux channel toggle, all four channels walked | **pass** — indices 1 and 2 populated |
| 3 | Part ID 0x15 on each channel | **pass** |
| 3b | INT line ↔ channel pairing verified | implemented in `selftest.c`, not yet run on hardware |
| 4 | Mount FAT, write and read back a test file | **fails at CMD0** — SPI wiring |
| 5 | Single-sensor logging, plausible waveform | acquires at ~100.5 Hz, `ovf=0`, `ri=0`; blocked on 4 for the logging half |
| 6 | Dual-sensor logging, no loss, no drift | pending |
| 7 | Multi-hour endurance run | pending |

---

## Command channel

The host can drive the hub over the same link it streams on — BLE RX
characteristic `6e400002-…`, or the USB console. `src/command.c` owns both.
The full grammar is in [protocol.md](protocol.md#1b-host--device-the-command-channel);
what matters here is how it stays out of acquisition's way.

- **Nothing parses in the BLE callback.** `on_rx_write()` hands bytes to
  `command_feed()`, which assembles lines under a spinlock and queues complete
  ones. File I/O there would stall the radio behind a card doing wear-levelling.
- **File system work happens on the storage thread**, between whole loop
  iterations, never mid-block. Response latency is therefore bounded by
  `CONFIG_PHYSDAQ_SD_SYNC_INTERVAL_MS` in the worst case — fine for something a
  human clicked, and not worth restructuring a timing-critical loop to improve.
- **`sd.abort` is recognised during line assembly**, not by the dispatcher. A
  download runs *inside* the command thread, so an abort routed the normal way
  could only be read once there was nothing left to abort.
- **Downloads yield between chunks.** Without that, a transfer holds the CPU for
  its full duration and the ~25 Hz live stream goes dead for minutes, which
  looks exactly like a crash.

USB needed an input path added — a `printk`-only build has none.
`CONFIG_CONSOLE_GETCHAR` provides one on the same CDC ACM device. If that ever
conflicts with `printk` on this device, dropping the symbol from `prj.conf`
disables only that thread and leaves BLE commands working.

### Erasing

`sd.format` unlinks `SESS*.BIN` rather than calling `fs_mkfs()`. Reformatting a
researcher's card because they clicked "erase" in a PPG app is a surprise nobody
wants; anything the firmware did not write is left alone.

`sd.format` refuses outright while a session is open. `sd.del` is narrower: it
refuses only the file currently open, so any *other* session can be deleted
mid-recording. Silently closing a recording because a listing was stale would
lose data the operator still believed was being captured.

Deletion runs in batches of 16 per call, re-walking the directory each time —
FATFS does not promise a stable iterator across unlinks. A card holding more
than 16 sessions therefore needs the command issued repeatedly; the reply's
remaining count is what tells you.

---

## Satellite roster

`src/satellites.c`. Up to 8 entries, each an address, a label and a source id
handed out from `PPG_SRC_REMOTE_BASE` (0x10). Stored in NVS on the board's
`storage_partition` — 32 kB at 0xEC000, which `xiao_ble_common.dtsi` reserves
for exactly this and which is clear of both the code partition and the UF2
bootloader. The whole roster is one NVS record: it is under 350 bytes, only ever
read and written whole, and a single record means an interrupted write cannot
leave half a roster behind.

**This is configuration and nothing else.** The hub does not scan for these
nodes, does not connect to them, and records nothing from them. `prj.conf`
enables `BT_PERIPHERAL` alone with `BT_MAX_CONN=1`; the hub never takes the
central role. What the roster buys today is that the assignment survives a power
cycle and lives on the hub rather than in one laptop's config file. The desktop
app carries a permanent banner saying so — a roster that looks like it is doing
something is worse than no roster at all.

Re-adding an address relabels the existing entry rather than consuming a second
slot, and keeps its source id: a session file recorded earlier refers to that
id.

---

## Phase 2 — not implemented

The format reserves `source_id` `0x10`+ and the header's `src_mux_ch` marks
non-local sources with `0xFF`, so remote streams can be written into the same
file without a format change. The roster above already hands out those ids.
What is missing is the radio path, and one question in front of it.

The load-bearing unknown is **time synchronisation**. Multi-site PPG
correlation is a timing measurement; if remote timestamps cannot be resolved
onto the hub's base with a bounded error below roughly one sample period
(10 ms at 100 Hz), the dataset does not answer the research question. Thread +
UDP is the intended direction — `zephyr,ieee802154` is already chosen in the
board devicetree and the `openthread` module is in the workspace — but no
mechanism has been designed or costed yet, and no error budget has been
established. That has to happen before the radio path is worth writing.

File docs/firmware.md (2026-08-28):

# Firmware Reference

Zephyr RTOS **v3.6.0** application for the XIAO nRF52840 Sense. Board name
`xiao_ble_sense`, CMake project `xiao_sense_app`. The Zephyr version is pinned in
`west.yml` so every teammate builds against the same tree.

For pinout, sensor registers and power hardware see
[hardware.md](hardware.md). For the output format see [protocol.md](protocol.md).

---

## Main loop

`firmware/src/main.c` is the whole application. Init order matters:

```
imu_init()  →  max30102_init()  →  battery_init()  →  contact_init()
            →  power_init()     →  ble_init()      →  watchdog_init()
```

The watchdog is armed **last**, deliberately: init can be slow (I2C probes, BLE
stack bring-up) and arming earlier would let a legitimate cold start trip it.
The boot banner and the `ID` line go out once init completes.

Each iteration then:

1. Feeds the watchdog.
2. Waits up to 200 ms for a PPG_RDY interrupt.
3. Drains the MAX30102 FIFO; for each PPG sample, fetches a matching IMU sample.
4. Formats **one** line and sends it to the USB console at full rate, and to BLE
   **rate-limited to one line per 40 ms (~25 Hz)** — the link carries about
   4 kB/s and 100 Hz would overflow the TX queue.
5. Re-sends the `ID` line if BLE has just become connected.
6. Updates contact detection and the idle/power state machine.
7. Polls the battery (internally rate-limited to once per 5 s).

Status and recovery messages are **dual-sent** the same way: the battery line,
the power line, the stall-recovery notice and the `ID` line all go to both the
console and BLE, so a wireless host sees the same diagnostics as a wired one.

### Two independent recovery mechanisms

These solve different failure modes and neither substitutes for the other:

**Watchdog — the CPU stopped.** `wdt0`, 8 s window, `WDT_FLAG_RESET_SOC`. Fed
at the top of the outer loop **and once per sample inside the FIFO-drain loop** —
that inner loop only exits once the FIFO is empty, and when a sample's worth of
work takes longer than the 10 ms sample period it never does, so an outer-only
feed reset a node that was streaming perfectly. Configured with
`WDT_OPT_PAUSE_HALTED_BY_DBG` but deliberately **not** `WDT_OPT_PAUSE_IN_SLEEP` —
the exact freeze it guards against idles the CPU on a `K_FOREVER` I2C wait, and
pausing in sleep would disarm it precisely when it is needed.

A kernel timer in `watchdog.c` watches the feeds: after 3 s without one it records
where `main()` is (the `watchdog_set_stage()` marker), what the kernel thinks of
it, and which thread holds the CPU with its PC — into noinit RAM via
`crashlog.c`, then to the console. The record survives the reset and is sent to
the host on the next boot as a `Hang:` line.

**Fatal errors — the CPU crashed.** Vanilla Zephyr's fatal handler ends in
`arch_system_halt()`: interrupts locked, spin forever. On this board that made a
crash indistinguishable from a hang: the dump sat in the USB CDC ring buffer with
the USB interrupt unable to run, the host saw a supervision timeout, the watchdog
reset 8 s later and the next boot said `cause=watchdog`. `crashlog.c` overrides
`k_sys_fatal_error_handler()` to store reason, PC, LR and thread in noinit RAM
and reboot at once; the next boot reports it as a `Crash:` line on both
transports (`Boot: cause=…` always accompanies it). Resolve addresses with
`arm-zephyr-eabi-addr2line -e build/zephyr/zephyr.elf 0x…`.

**Sensor-stall recovery — the CPU is fine, the sensor isn't.** If the FIFO yields
nothing for more than 1 s, `max30102_init()` is re-run. This recovers the I2C bus
and fully reconfigures the chip. The watchdog cannot help here because the main
loop is still happily turning over; without this check the whole pipeline
(serial + BLE + power management) would sit frozen while the MCU looked healthy.

---

## Modules

| File | Responsibility |
|---|---|
| `main.c` | Init sequence, acquisition loop, line formatting, stall recovery |
| `max30102.c/.h` | Register-level I2C driver for the PPG front end |
| `imu.c/.h` | Thin wrapper over Zephyr's `st_lsm6dsl` driver |
| `ble.c/.h` | NUS-compatible GATT service, advertising, MTU negotiation |
| `power.c/.h` | Idle detection, deep sleep, wake-on-motion configuration. Reads DTR on the CDC console (`CONFIG_UART_LINE_CTRL`) so a host holding the USB port open holds off sleep like a BLE link does |
| `contact.c/.h` | Skin-contact detection from the IR DC level |
| `battery.c/.h` | VBAT sampling and LiPo state-of-charge curve |
| `watchdog.c/.h` | Hardware watchdog arm + feed, plus the starvation monitor (kernel timer) |
| `crashlog.c/.h` | Fatal-error handler override, noinit-RAM crash/hang records, reported on the next boot |
| `led.c/.h` | RGB helper over the three onboard LEDs |
| `version.h` | `PHYSDAQ_FW_STRING` — the single source for the `ID` line and, on the hub, session-file headers |

### `max30102.c`

Custom driver — there is no Zephyr native MAX30102 driver in use. Covers
registers 0x00–0x0D plus 0xFF (part ID, verified as `0x15` at init).

The interrupt handler gives a `K_SEM`. `max30102_wait_ready(timeout)` ignores the
semaphore take result and **always** clears `INT_STATUS1`, so a missed falling
edge costs one timeout of latency rather than a permanent stall — the timeout
path is a normal, self-healing branch, not an error.

`max30102_fetch()` compares the FIFO write and read pointers and burst-reads
6 bytes (3 Red + 3 IR), masking to 18 bits. Returns `-ENODATA` when the FIFO is
empty, which is how the drain loop terminates.

`max30102_shutdown()` puts the chip in SHDN for the sleep path.

### `ble.c`

The NUS service is built from **raw Zephyr GATT macros**, not `CONFIG_BT_NUS` —
that symbol is Nordic Connect SDK-only and does not exist in plain Zephyr.

- Advertises the 128-bit service UUID in the AD payload and the device name in
  the scan response, so hosts can filter by UUID.
- Also advertises a **manufacturer-specific field** under company ID `0xFFFF`
  carrying four bytes — AD protocol version, device type (`0x01` node, `0x02`
  hub), PPG count, and a flags byte whose bit 0 means "has an SD card". That
  brings the AD payload to 29 of the 31 available bytes. It is a **hint for the
  host's scan list only**: discovery still filters on the service UUID, and the
  `ID` line is what actually decides once connected.
- Names itself `PhysDAQ-XXXX` at boot from the factory device ID, so a scan can
  tell two nodes apart. Needs `CONFIG_BT_DEVICE_NAME_DYNAMIC` and
  `CONFIG_HWINFO`; if hwinfo fails it falls back to the plain configured name
  rather than refusing to advertise.
- Requests an MTU exchange on connect and logs the negotiated value.
- `ble_send()` **never touches the radio.** It copies the line into a bounded
  message queue (16 × 160 B, `K_NO_WAIT`, dropped when full — `ble_tx_dropped()`
  counts them, shown as `dropped N` in the `Power:` line) and a dedicated
  low-priority TX thread drains it, chunking by `MTU − 3`. This is not a style
  choice: `bt_gatt_notify()` allocates its PDU with `K_FOREVER`
  (`zephyr/subsys/bluetooth/host/att.c`, `bt_att_chan_create_pdu`) and blocks
  indefinitely once the ACL TX buffers are exhausted. Called from `main()`, that
  sleep starved the watchdog and reset the node mid-session.
- The controller runs LL Data Length Extension (`CONFIG_BT_CTLR_DATA_LENGTH_MAX=251`).
  Without it the 27 B LL default split each ~120 B line into five packets and
  saturated the link at Windows' 30 ms interval. TX pools are 6 deep.
- `CONFIG_BT_GAP_AUTO_UPDATE_CONN_PARAMS` is **off**. With it on, the node crashed
  within a second of the central applying the update, every time, on Windows.
  The `BT_PERIPHERAL_PREF_*` values are kept in `prj.conf` for when that is
  understood.
- Re-advertises automatically on disconnect, and remembers the HCI reason. It
  is sent to the host on the next connection (`BLE: previous link ended
  reason=…`) via `ble_flush_diagnostics()`, called from the main loop — the
  callbacks only record, they never notify. The granted connection parameters
  are reported the same way.
- `ble_stop()` shuts the controller down cleanly before System Off.
- `ble_is_connected()` reports link state — the power state machine uses it as a
  "do not sleep" condition. `ble_is_subscribed()` additionally requires the CCC
  write, and that is the edge `main.c` watches to re-send the `ID` line: on the
  bare connection edge the host has not enabled notifications yet and the line
  was silently dropped.
- `ble_device_name()` returns the resolved `PhysDAQ-XXXX` name for the `ID` line.
- A `le_param_updated` callback logs the interval the central actually granted,
  which is the only way to tell a negotiated connection from a requested one.
- The RX characteristic (host → device) is registered but its handler is a no-op
  on this firmware. The hub wires the same characteristic to its command parser —
  see [firmware-hub.md](firmware-hub.md#command-channel) — so extending the node
  is a matter of reusing that code, not designing a channel.

The node emits an identity line at boot and again whenever a host connects:

```
ID model=node proto=2 fw=1.2.0 ppg=1 sd=0 name=PhysDAQ-FDF9
```

Field meanings are in [protocol.md](protocol.md#identity-line). The version comes
from `version.h`, which is also what stamps the hub's session-file headers, so
the two can never disagree.

### `led.c`

Compiled and functional, but **not currently called from `main.c`** — the status
LEDs are unused. Kept because a wearable with no display wants some local status
indication eventually; see [roadmap.md](roadmap.md).

---

## Configuration

### `firmware/prj.conf`

| Symbol | Purpose |
|---|---|
| `CONFIG_GPIO`, `CONFIG_SERIAL`, `CONFIG_UART_CONSOLE` | Console plumbing |
| `CONFIG_I2C`, `CONFIG_SENSOR`, `CONFIG_LSM6DSL` | IMU |
| `CONFIG_ADC` | VBAT sensing |
| `CONFIG_WATCHDOG` | Hardware watchdog |
| `CONFIG_PHYSDAQ_IDLE_TIMEOUT_SEC` | Seconds before deep sleep (default 10) |
| `CONFIG_BT`, `CONFIG_BT_PERIPHERAL` | BLE stack |
| `CONFIG_BT_DEVICE_NAME="PhysDAQ"` | Advertised name |
| `CONFIG_BT_DEVICE_NAME_DYNAMIC`, `CONFIG_BT_DEVICE_NAME_MAX=24`, `CONFIG_HWINFO` | Per-device `PhysDAQ-XXXX` naming at boot |
| `CONFIG_BT_GAP_AUTO_UPDATE_CONN_PARAMS=y` | What makes the `PREF_*` row below take effect at all |
| `CONFIG_BT_MAX_CONN=1` | One central at a time |
| `CONFIG_BT_GATT_CLIENT=y` | Needed for `bt_gatt_exchange_mtu()` **even on a peripheral** |
| `CONFIG_BT_L2CAP_TX_MTU=247`, `CONFIG_BT_BUF_ACL_*_SIZE=251` | Fit a full data line in one notification |
| `CONFIG_BT_CTLR_TX_PWR_PLUS_8=y` | +8 dBm radio — margin against body shadowing on a worn node |
| `CONFIG_BT_PERIPHERAL_PREF_*` | Request 15–30 ms interval + **5 s supervision timeout** so a radio fade degrades throughput instead of dropping the link |

### `firmware/Kconfig`

Declares `PHYSDAQ_IDLE_TIMEOUT_SEC`, default 10, **range 5–300**, with help text.
Changing a Kconfig symbol requires `make rebuild` (pristine), not `make build`.

### `firmware/boards/xiao_ble_sense.overlay`

Adds the `max30102@57` node to `&i2c1` with
`int-gpios = <&gpio0 3 (GPIO_ACTIVE_LOW | GPIO_PULL_UP)>`, declares the
`battery_divider` voltage-divider node, enables `&wdt0`, and configures ADC
`channel@7` (gain 1/6, internal reference, 12-bit, `NRF_SAADC_AIN7`).

The custom binding at `firmware/dts/bindings/sensor/maxim,max30102.yaml` is made
visible by `list(APPEND DTS_ROOT …)` in `CMakeLists.txt`, which must appear
**before** `find_package(Zephyr)`.

---

## The console is USB, not a UART

`prj.conf` only sets `CONFIG_UART_CONSOLE`, which reads like a physical UART. It
is not. The board's `xiao_ble_common.dtsi` sets
`zephyr,console = &usb_cdc_acm_uart`, so the console is a **USB CDC ACM virtual
COM port**.

Consequences worth knowing:

- The 115200 baud rate everything quotes is nominal — it is ignored by USB.
- The COM port **disappears** when the node enters deep sleep and reappears as a
  fresh port on wake. Reconnect `make term` (or the desktop app) afterwards.
- Flow control is USB's, not the UART's, so the device can block on a host that
  stops reading.

---

## Building

```bash
make build      # incremental
make rebuild    # pristine — required after overlay/DTS/Kconfig changes
make flash      # double-tap RST, then copy build/zephyr/zephyr.uf2
make term       # console
```

`scripts/build-wrapper.py` sits in front of `west build` and auto-detects stale
CMake caches that reference an external Nordic SDK path (`C:/ncs/...`), purging
them instead of failing with an opaque `pristine.cmake` error.

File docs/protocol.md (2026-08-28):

# Data Contracts

Three formats hold this system together. They are the real interfaces between
firmware, bridge, desktop app and analysis code — change one and something
downstream breaks, so they are documented here in one place.

1. [Device → host: the ASCII line protocol](#1-device--host-ascii-line-protocol)
2. [Host → device: the command channel](#1b-host--device-the-command-channel)
3. [Bridge → app: JSON on stdout](#2-bridge--app-json-lines)
4. [App → disk: the session CSV](#3-app--disk-session-csv)

Plus [the logger CSV](#4-logger-csv-analysis-input), which is a fourth, older
format the offline pipeline consumes.

---

## The chain

```mermaid
flowchart TB
  subgraph DEV["Sensor node or hub — Zephyr 3.6 · nRF52840"]
    direction TB
    SENS["MAX30102 × 1 (node) / × 2 (hub, behind an I2C mux)<br/>LSM6DS3TR-C IMU on i2c0"]
    LOOP["100 Hz acquisition loop"]
    SD["microSD — hub only<br/>storage thread, 512 B blocks"]
    SENS --> LOOP
    LOOP --> SD
  end

  BR["<b>BRIDGE</b> · scripts/bridge.py<br/>parse · per-channel DSP · AHRS fusion +ZUPT · FFT heart rate"]
  APP["<b>DESKTOP APP</b> · app/ — Electron · React · Vite<br/>body map · live charts · 3D orientation · recording<br/>hub: SD browse / erase / download · satellite roster"]
  CSV[("CSV — one per body position, per session")]
  AN["<b>OFFLINE ANALYSIS</b> · analysis/<br/>motion cancellation · beat detection · HRV (RMSSD) · SpO2 · explorer"]

  LOOP -- "USB CDC ACM · 100 Hz<br/>or BLE (NUS) · ~25 Hz<br/>ASCII: <code>PPG red=… ir=… | IMU ax=…</code>" --> BR
  BR -- "ASCII: <code>CMD sd.list</code>, <code>CMD rec.stop</code>" --> LOOP
  BR -- "JSON on stdout" --> APP
  APP -- "commands on stdin" --> BR
  APP --> CSV
  CSV --> AN
```

> **No mesh.** Nodes do not talk to each other, and neither does the hub — it
> carries two of its own sensors, not other people's. Each device is an
> independent BLE peripheral / USB CDC device; multi-node aggregation happens
> entirely on the host, one bridge process per device. A hub's satellite roster
> is configuration the hub remembers, not a link it uses.

The bridge is shipped two ways: run straight from source during development, and
frozen with PyInstaller into a standalone binary for installed copies of the app,
so end users never install Python.

---

## 1. Device → host: ASCII line protocol

Both transports carry **exactly the same** newline-delimited ASCII. The BLE path
is not a separate binary protocol — `firmware/src/main.c` formats each line once
and hands the same buffer to `printk()` and `ble_send()`.

| | USB | BLE |
|---|---|---|
| Carrier | USB CDC ACM virtual COM port, 115200 8N1 (nominal) | Nordic UART Service notifications |
| Rate | 100 Hz (every sample) | ~25 Hz (one line per 40 ms) |

The BLE path is rate-limited on purpose: a BLE link at default Windows connection
parameters carries roughly 4 kB/s, while 100 Hz × ~120 B would be 12 kB/s and
overflows the TX queue immediately. USB gets every sample; BLE gets a display-rate
subset.

### Sample line

A single-PPG node:

```
PPG red=<uint> ir=<uint> | IMU ax=±D.DDD ay=±D.DDD az=±D.DDD gx=±D.DDD gy=±D.DDD gz=±D.DDD
```

A dual-PPG hub, which inserts one extra section and is otherwise identical:

```
PPG red=<uint> ir=<uint> | PPG1 red=<uint> ir=<uint> | IMU ax=±D.DDD …
```

| Field | Range / unit |
|---|---|
| `red`, `ir` | 0 … 262143 (18-bit ADC counts) |
| `ax` `ay` `az` | m/s² |
| `gx` `gy` `gz` | **rad/s** (Zephyr sensor API — not deg/s) |

Numbers are formatted as fixed 3-decimal "integer.milli" from
`sensor_value.val1`/`val2`. A node's line is about 120 bytes and a hub's about
144; the node's firmware buffer is 160, the hub's 192.

> **The `PPG red=` prefix is load-bearing, and one line is not two.** The bridge
> matches with `re.search`, so a hub's line still yields sensor 0 to a bridge
> that knows nothing about `PPG1` — old host, new firmware, still works. The
> reverse trick does not: the parser **silently discards** any unmatched line
> beginning with `PPG`, so a separate `PPG1 …` line would vanish without trace.
> Keeping both sensors in one message also gives the pair one arrival timestamp,
> which is the only thing tying the two channels together in time on the host.
>
> Nothing else on either stream may start with `PPG` — not the `Hub:` status
> line, not any command reply. That is why they are prefixed the way they are.

### Identity line

Emitted at boot and again on every new BLE connection, on both transports:

```
ID model=hub proto=2 fw=1.2.0 ppg=2 sd=1 name=PhysDAQ-Hub-FDF9
```

| Field | Meaning |
|---|---|
| `model` | `node` or `hub` |
| `proto` | identification protocol version (this is 2) |
| `fw` | firmware version, from `src/version.h` |
| `ppg` | PPG channel count — how many the sample line will carry |
| `sd` | `1` when a card is mounted and usable, `0` otherwise |
| `name` | the advertised name, so USB and BLE views agree |

**This is the authority on what a device is.** The advertisement carries the
same device class (see *BLE identifiers* below), but USB has no advertising at
all, so a cabled device is unidentifiable without this line. It is re-sent on
every connection because a central that connects late missed the boot copy —
and on USB, where the CDC ACM port does not exist yet while the board boots, the
boot copy is routinely lost too. `CMD id` asks for it on demand.

### Auxiliary lines on the same stream

Everything below shares the stream with sample lines. The bridge matches sample
and battery lines with regexes and forwards **all other lines to stderr**, which
the desktop app surfaces in its System Logs pane.

> **USB vs BLE:** `printk()` only reaches the USB console. The battery line, the
> periodic `Power:` status, the MAX30102 reinit message and the two BLE link
> diagnostics (`previous link ended`, `conn params`) are explicitly dual-sent
> over BLE so a wireless node still streams diagnostics to the app; every other
> line (boot banner, BLE events, watchdog) is USB-only.

```
Battery: 71% (3940 mV)
Power: idle 4s/10s | skin: yes (dc=29050) | ble: yes (dropped 12) | usb: no | peak ~12mrad/s (thresh 100mrad/s)
Power: 10 s idle — entering deep sleep (wake on motion)
MAX30102: ready (SpO2, 100 Hz, 18-bit ADC)
MAX30102: no data for >1s — reinitialising sensor
BLE: connected
BLE: MTU 247 bytes (244 payload)
BLE: conn params: interval 30 ms, latency 0, timeout 5000 ms
BLE: previous link ended reason=0x08 (supervision timeout (radio fade))
Boot: cause=0x4 (software (fatal error or reboot)), up 0 s
Crash: stack overflow (reason 2) in ble_tx pc=0x0002a1c4 lr=0x0002a0f1
Hang: main starved 3012 ms at stage "printk" (main pending); CPU held by "BT RX" prio -8 pc=0x00031b20
BLE: disconnected (reason 0x13 closed by host) — advertising
Watchdog: armed (8000 ms, reset-on-hang)
```

The **boot report** — `Boot:` always, `Crash:` and/or `Hang:` only when the
previous boot ended that way — follows the `ID` line on every new host link
(BLE subscription or USB port opened). `Boot: cause=` is the nRF reset reason:
`watchdog`, `software` (a fatal error that `crashlog.c` turned into a reboot),
`wake from deep sleep`, `reset pin`, `power-on`. `Crash:` names the fault and the
thread with PC/LR; `Hang:` says where `main()` was stuck and which thread held
the CPU when the starvation monitor fired 3 s before the watchdog reset. A node
that "keeps disconnecting" and shows any of these is rebooting, not losing the
radio — read them before touching the link parameters. `dropped N` in the
`Power:` line counts BLE lines the node sacrificed because its TX queue was
full; a steady number is normal, a jump of hundreds is a stall.

`BLE: previous link ended` is sent once, on the first connection after a link
was lost, and is the only place the *cause* of a drop is visible from the app —
the OS side (bleak) never reports one. The codes are HCI reasons: `0x08`
supervision timeout (the radio faded or the node reset), `0x13` the host closed
it, `0x16` the node closed it, `0x3e` connection failed to establish. The bridge
logs its own side (`BLE: link to … dropped (reported by the OS N s after the
last notification)`) so the two can be lined up, and drops a link itself after
8 s without a notification (`BLE: no data for 8 s — dropping the link to
reconnect`) rather than sitting on a connection the OS has not noticed is dead.

Plus the boot banner:

```
=== PhysDAQ: PPG + IMU acquisition ===
PPG: SpO2 mode, 100 Hz, 18-bit ADC
IMU: accel [m/s^2], gyro [rad/s]
BLE: NUS advertising as PhysDAQ
Battery: VBAT via P0.31/AIN7, sampled every 5 s
Power: sleep after 10 s idle
```

### BLE identifiers

Stock Nordic UART Service UUIDs — the device does not define custom ones:

| Role | UUID |
|---|---|
| Service | `6e400001-b5a3-f393-e0a9-e50e24dcca9e` |
| TX (device → host, notify) | `6e400003-b5a3-f393-e0a9-e50e24dcca9e` |
| RX (host → device, write w/o response) | `6e400002-b5a3-f393-e0a9-e50e24dcca9e` |

The advertised name is `PhysDAQ-XXXX`, where the suffix is the last two bytes of
the SoC's factory device ID (`hwinfo_get_device_id()`), so two nodes are
distinguishable in a scan. It is derived at boot rather than stored — this board
has no NVS configured — and is stable across reboots and reflashes because the
ID is burned into FICR.

**No host code matches on the name.** Every Python client discovers by service
UUID, which is advertised in the AD payload precisely so scanners can filter on
it; `bridge.py --scan` does exactly that. Renaming the device does not break
discovery. The desktop app can additionally attach a user-chosen alias to an
address, but that lives host-side in `nodes.json`, not on the node.

### Device class in the advertisement

Alongside the service UUID, the AD carries a manufacturer-specific field under
company ID `0xFFFF` — the Bluetooth SIG's reserved "local use" value, which is
what this is: a private hint, not an assigned identifier. bleak strips the
company ID and hands the host the rest:

| Byte | Meaning |
|---|---|
| 0 | AD protocol version (2) |
| 1 | device type — `0x01` node, `0x02` hub |
| 2 | PPG channel count |
| 3 | flags — bit 0: has removable storage |

This exists so the scan list can label an entry **before** connecting. It does
not change how discovery works: the filter is still the service UUID, never this
field and never the name. Once connected, the ID line is what decides.

Firmware older than protocol 2 omits the field; a host that finds it missing or
unreadable reports a single-PPG node. That fallback direction is deliberate —
under-reporting a hub is corrected by the ID line seconds later, whereas guessing
"hub" would have the app wait for a second channel that never arrives.

Payload budget: 3 (flags) + 18 (128-bit UUID) + 8 (manufacturer data) = 29 of the
31 bytes allowed. The name goes in the scan response, not here.

---

## 1b. Host → device: the command channel

The RX characteristic `6e400002-…` used to be a no-op. It now carries
newline-terminated ASCII commands, as does the USB console (which needed an
input path added: `CONFIG_CONSOLE_GETCHAR`). Replies come back on the normal
output stream, interleaved with samples.

Implemented on the **hub only** — `firmware-hub/src/command.c`. The single-PPG
node still has a no-op handler.

### Requests

```
CMD id                      re-send the identity line
CMD sd.stat                 card usage and session state
CMD sd.list                 enumerate session files
CMD sd.del <name>           delete one session file
CMD sd.format               delete every session file
CMD rec.start               open the next session file
CMD rec.stop                close the current session file
CMD sd.get <name> [offset]  stream a session file back, base64
CMD sd.abort                stop an in-flight sd.get
CMD sat.list                list configured satellites
CMD sat.add <addr> [label]  remember a satellite
CMD sat.del <addr>          forget one
CMD sat.clear               forget all
```

`sd.abort` is recognised during line assembly rather than by the dispatcher.
It has to be: a download runs inside the command thread, so a request routed the
normal way could only be read once there was nothing left to abort.

### Replies

```
SD stat mounted=1 used=12345678 total=31914983424 sess=4 open=1 w=2400 drop=0 err=0
SD stat mounted=0 err=<errno>
SD file SESS0001.BIN 5242880
SD list end n=3
SD ok <verb> [<detail>]
SD err <verb> <errno>
SD data <name> <offset> <len> <base64>
SD data end <name> <total> crc=<crc32>
SD data abort <name> <offset>
REC state=on sess=5
REC state=off
SAT n=2 max=8
SAT entry 0 addr=E1:23:45:67:89:AB src=0x10 label=wrist_L
SAT list end
SAT ok <verb> [<detail>]
SAT err <verb> <errno>
```

Errno values are numbers, not strings, so the host can branch on them. The ones
that carry meaning: `ENODEV` (19) no card, `EBUSY` (16) a session is open,
`EINVAL` (22) bad filename or address, `ENOSPC` (28) roster full.

### Download

`sd.get` streams the file as base64 over the same ASCII lines as everything
else. That costs 33 % in size, and the transfer shares the link with the live
sample stream: **a one-hour session is roughly 11 MB, so about 50 minutes over
BLE and 20 over USB CDC.** Prefer USB, and show the estimate before starting.

The firmware yields between chunks so the sample stream keeps flowing — without
that the live view would go dead for the whole transfer, which looks exactly
like a crash. The trailing CRC32 is what distinguishes a complete file from one
missing a dropped chunk; `sd.get` takes an offset so an interrupted transfer can
resume rather than restart.

The bridge writes the file itself and never forwards the bytes to the app: a
one-hour session through Electron IPC and into React state would cost far more
than the transfer. Only progress is reported.

That inversion is the thing to keep in mind — the request crosses every layer,
but the payload leaves the chain at the bridge:

```mermaid
sequenceDiagram
  participant R as Renderer
  participant M as Electron main
  participant B as Bridge
  participant F as Firmware
  participant D as Disk

  R->>M: send-device-command(id, {cmd: "sd.get", file})
  Note over M: main fills in dest —<br/>the renderer cannot choose the path
  M->>B: stdin JSON + dest
  B->>F: CMD sd.get <file> <offset>
  loop until complete
    F-->>B: SD data <base64 chunk>
    B->>D: append decoded bytes
    B-->>M: sd_progress
    M-->>R: sensor-data (sd_progress)
  end
  F-->>B: SD done <crc32>
  B->>D: close, verify CRC
  B-->>M: sd_result
  M-->>R: sensor-data (sd_result)
```

Files land in `Documents/PhysDAQ_Sessions/hub_downloads/`. Nothing in this
repository parses them yet — see [roadmap.md](roadmap.md).

### Satellites

`sat.*` is **configuration only**. The hub stores the roster in NVS and reports
it; it does not scan for these nodes, connect to them, or record anything from
them. `prj.conf` enables `BT_PERIPHERAL` alone with `BT_MAX_CONN=1`, and the hub
never takes the central role. See [firmware-hub.md](firmware-hub.md) for why
ingestion is not implemented.

---

## 2. Bridge → app: JSON lines

`scripts/bridge.py` writes one JSON object per line to stdout, flushed
immediately.

### `sample`

```json
{
  "type": "sample",
  "red": 28451, "ir": 29033,
  "ppg_filt": -12.47,
  "ax": 0.213, "ay": -9.706, "az": 0.884,
  "gx": 0.001, "gy": -0.004, "gz": 0.002,
  "quat": [0.9993, 0.0121, -0.0344, 0.0058],
  "bpm": 72.4,
  "contact": true,
  "ch": [
    {"i": 0, "red": 28451, "ir": 29033, "ppg_filt": -12.47, "bpm": 72.4, "contact": true},
    {"i": 1, "red": 11072, "ir": 11840, "ppg_filt":   3.02, "bpm": 71.8, "contact": true}
  ]
}
```

- `quat` is `[w, x, y, z]` in the **NWU** convention (North-West-Up, Z up).
- `bpm` is `null` when there is no contact or no confident spectral peak.
- `ppg_filt` is the AC component of the IR channel after a single-sample EMA
  band-pass; it is what the app's main waveform chart displays.
- **`ch` is additive, and the top level is channel 0.** A node emits one entry,
  a hub two. Keeping channel 0 duplicated at the top level is what lets the CSV
  writer, the charts and the recording schema stay exactly as they were.
- Each channel carries its **own** BPM, contact state and filter baseline. A
  hub's two sensors sit at different body sites; sharing any of that between
  them would blend two unrelated pulses into one meaningless number. The
  quaternion and IMU stay shared — there is one IMU per board.

### `identity`

```json
{"type": "identity", "model": "hub", "proto": 2, "fw": "1.2.0",
 "ppg_count": 2, "has_sd": true, "name": "PhysDAQ-Hub-FDF9", "source": "device"}
```

`source` is `device` when parsed from the ID line and `cli` when it came from
`--device-type=`, which the app passes so the UI can lay out two channels
before the first sample arrives. The device's own line supersedes it.

### `hub_status`

The hub's 5-second health line, parsed rather than dumped to stderr:

```json
{"type": "hub_status", "uptime_s": 3600,
 "sensors": [{"i": 0, "alive": true, "samples": 360000, "rate_hz": 100.0,
              "overflows": 0, "reinits": 0, "ir": 29033}],
 "sd": {"sess": 4, "open": 1, "w": 719000, "drop": 0, "sync": 3600, "err": 0, "qmax": 64},
 "satellites": {"n": 2, "max": 8}}
```

`drop` and `err` are the numbers to watch on an endurance run; both should stay
at zero.

### Command replies

One shape per reply family, all mirroring section 1b:

```json
{"type": "sd_stat", "mounted": true, "used": 12345678, "total": 31914983424, "sess": 4, "open": 1}
{"type": "sd_file", "name": "SESS0001.BIN", "size": 5242880}
{"type": "sd_list_end", "n": 3}
{"type": "sd_result", "verb": "sd.del", "ok": true, "detail": "SESS0002.BIN"}
{"type": "sd_result", "verb": "sd.format", "ok": false, "errno": 16}
{"type": "sd_progress", "file": "SESS0001.BIN", "bytes": 1048576}
{"type": "rec_state", "recording": true, "session": 5}
{"type": "sat_begin", "n": 2, "max": 8}
{"type": "sat_entry", "slot": 0, "addr": "E1:23:45:67:89:AB", "source_id": 16, "label": "wrist_L"}
{"type": "sat_end"}
{"type": "sat_result", "verb": "sat.add", "ok": true}
```

Listings stream entry by entry and are terminated by `sd_list_end` / `sat_end`.
The app accumulates into a pending list and swaps it in only on that terminator,
so a listing cut short by a disconnect cannot be mistaken for an empty card.

`sd_result` carries a device-reported failure in `errno` (a number, as in
section 1b). Failures that happen **host-side** — before the device ever answers,
or because the transfer was cancelled — use a string `error` instead, and the
successful case sets `"error": null`:

```json
{"type": "sd_result", "verb": "sd.get",  "ok": false, "file": "SESS0001.BIN", "error": "aborted"}
{"type": "sd_result", "verb": "sd.list", "ok": false, "error": "not connected"}
{"type": "sd_result", "verb": null,      "ok": false, "error": "<write failure>"}
```

The third form — `verb: null` — is a BLE write that threw before the verb could
be attributed. A host matching on `verb` will not see it, so branch on `ok`
first.

A finished download reports both checksums so a mismatch is visible rather than
inferred:

```json
{"type": "sd_result", "verb": "sd.get", "ok": true, "file": "SESS0001.BIN",
 "path": "C:\Users\...\PhysDAQ_Sessions\hub_downloads\SESS0001.BIN",
 "bytes": 5242880, "expected": 5242880, "crc": "97d0ab42", "device_crc": "97d0ab42"}
```

### `battery`

```json
{"type": "battery", "pct": 71, "mv": 3940}
```

### `status`

```json
{"status": "connecting"}
{"status": "connected",   "port": "COM7"}
{"status": "connected",   "ble_addr": "E1:23:45:67:89:AB"}
{"status": "disconnected"}
```

`connecting` never carries a target — the bridge emits it before it knows which
port or address it will end up on. `port` appears on a serial `connected`,
`ble_addr` on a wireless one.

The bridge retries on its own after a `disconnected`, so a dropped link produces
`disconnected` → `connecting` → `connected` without the app doing anything. The
process itself lives until its stdin closes, at which point it exits
immediately — that is what guarantees no orphaned serial port when the app
quits.

### `error`

```json
{"error": "bleak not installed"}
```

Anything the bridge cannot parse from the device goes to **stderr**, prefixed
`FW: `, and is displayed in the app rather than being silently dropped. The one
exception is the `PPG`-prefixed discard rule above: an unmatched line starting
with `PPG` is dropped without a trace.

The bridge also writes its own diagnostics to the same stream, unprefixed — the
periodic `Link rate: N samples/s`, and `Serial:` / `BLE:` / `Bridge:` / `AHRS:`
notices. They share the app's System Logs pane with the firmware's own output.

### Bridge invocation

| Argument | Behaviour |
|---|---|
| *(none)* | Serial, port auto-detected by USB descriptor |
| `<PORT>` | Serial on an explicit port |
| `--ble` | BLE, first device advertising the NUS UUID |
| `--ble-addr=<addr>` | BLE, specific address |
| `--device-type=hub` | Expect two PPG channels without waiting for the ID line |
| `--list-ports` | Print `[{port, desc, hwid}]` and exit |
| `--scan` | Print `[{address, name, rssi, device_type, ppg_count, has_sd}]` and exit |
| `--scan-all` | Same, without the service-UUID filter |

### stdin: the command channel

The app writes one JSON command per line to the bridge's stdin; the bridge
translates it into the firmware's `CMD …` grammar and writes it to the RX
characteristic or the serial port.

```json
{"cmd": "sd.list"}
{"cmd": "sd.del", "file": "SESS0002.BIN"}
{"cmd": "sd.get", "file": "SESS0001.BIN", "dest": "C:\...\SESS0001.BIN", "offset": 0}
{"cmd": "sat.add", "addr": "E1:23:45:67:89:AB", "label": "wrist_L"}
```

`dest` is host-side only — the firmware never sees it. The main process fills
it in, so the renderer cannot choose where a file lands.

The bridge still exits on stdin **EOF**, which is how the desktop app guarantees
no orphaned processes keep a serial port or BLE link open. Reading line by line
did not change that.

---

## 3. App → disk: session CSV

Written by `app/src/main/sidecar.ts` while recording.

**Location:** `Documents/PhysDAQ_Sessions/session_<ISO-date>_<name>/<position>.csv`

- The ISO timestamp has `:` and `.` replaced by `-` to be filesystem-safe.
- `<name>` is the user's session name with everything outside `[A-Za-z0-9_-]`
  replaced by `_`.
- `<position>` is the body slot: `head`, `chest`, `wrist_left`, `wrist_right`,
  `finger_left`, `finger_right`, `ankle_left`, `ankle_right`. **One file per
  body-position slot**, all sharing a common session start time.

> **A hub writes two files, not one.** Its two PPG sensors are worn at two
> different sites, so it claims two slots and each gets its own CSV in the
> unchanged 17-column schema — indistinguishable from a node's. What differs is
> that the two files share an IMU: their `ax…gz` and quaternion columns are
> identical, and only the `ppg_*`, `bpm` and `contact` columns differ. The
> recording map is keyed on the slot rather than on the device precisely so this
> falls out without a schema change.

**Header (17 columns):**

```
timestamp,elapsed_s,ax,ay,az,gx,gy,gz,qw,qx,qy,qz,ppg_red,ppg_ir,ppg_filt,bpm,contact
```

| Column | Notes |
|---|---|
| `timestamp` | ISO-8601 **string** — host arrival time, written by the app. The device sends no clock of its own, so this is the only time base in the file, and it carries the link's latency. |
| `elapsed_s` | seconds since session start, float |
| `ax…gz` | as on the wire (m/s², rad/s) |
| `qw qx qy qz` | orientation quaternion, NWU |
| `ppg_red`, `ppg_ir` | raw 18-bit counts |
| `ppg_filt` | band-passed IR AC component |
| `bpm` | **blank** when unavailable |
| `contact` | `0` or `1` |

> Sessions recorded before the project was renamed live in
> `Documents/MAID_Sessions`. The app still lists them read-only; it only ever
> writes to `PhysDAQ_Sessions`.

Files pulled off a hub's card land in
`Documents/PhysDAQ_Sessions/hub_downloads/` — a sibling of the session folders,
not one of them. They are raw `.BIN` in the format
[firmware-hub.md](firmware-hub.md) documents, and nothing in this repo reads
them yet.

---

## 4. Logger CSV (analysis input)

`analysis/logger.py` writes a **different, older and simpler** format to
`logs/YYYY-MM-DD_HH-MM-SS.csv`:

```
timestamp,red,ir,ax,ay,az,gx,gy,gz
```

Here `timestamp` is a **float** (seconds), and the PPG columns are `red`/`ir`,
not `ppg_red`/`ppg_ir`.

> ⚠️ **These two CSV formats are not interchangeable.** `analysis/pipeline.py`
> does `pd.read_csv(path).astype(float)` and expects the logger schema — it will
> raise on an app-recorded session's ISO timestamp, and the `red`/`ir` columns it
> wants do not exist there. There is currently no converter in the repo. See
> [roadmap.md](roadmap.md).

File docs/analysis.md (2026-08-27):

# Analysis Pipeline

Offline processing for recorded PhysDAQ data: filtering, motion cancellation,
orientation, beat detection, HRV and SpO2. Everything here is host-side Python
under `analysis/`.

There are three tools, meant to be used in order:

```bash
make log                              # 1. record  → logs/YYYY-MM-DD_HH-MM-SS.csv
make process FILE=logs/<file>.csv     # 2. process → *_enriched.csv, *_beats.csv
make explore FILE=logs/<file>.csv     # 3. inspect interactively
```

`make ble-log` does the same as `make log` over Bluetooth instead of USB.

---

## 1. `analysis/logger.py` — recording

Writes the raw stream to `logs/YYYY-MM-DD_HH-MM-SS.csv` with the header:

```
timestamp,red,ir,ax,ay,az,gx,gy,gz
```

`timestamp` is a float in seconds. Works over serial or BLE; BLE discovery is by
NUS service UUID, never by device name.

> **The logger records one channel of a hub.** Its regex mirrors the bridge's:
> the hub's `| PPG1 red=… ir=…` section is optional and its groups are dropped,
> because this CSV *is* the pipeline's single-channel input schema. `make log`
> against a hub therefore works, prints a one-line notice, and writes sensor 0
> only. Record from the desktop app to capture both of a hub's sensors.

---

## 2. `analysis/pipeline.py` — processing

Reads one logger CSV, writes three siblings next to it:

| Output | Contents |
|---|---|
| `<stem>_enriched.csv` | per-sample derived signals and orientation |
| `<stem>_beats.csv` | per-heartbeat metrics |
| `<stem>_bpm_spectral.csv` | sliding-window spectral heart rate |

**Enriched columns:** `red_filt`, `ir_filt`, `ir_clean`, `red_clean`, `red_dc`,
`ir_dc`, `roll_deg`, `pitch_deg`, `yaw_deg`, `qw`–`qz`, `accel_mag_g`, `motion`,
`contact`.

**Beat columns:** `beat_time`, `ibi_ms`, `bpm`, `rmssd_ms`, `spo2_pct`,
`motion_artifact`.

### Stages

1. **Band-pass / low-pass** the PPG channels.
2. **Contact mask** from the IR DC level.
3. **Madgwick AHRS** → quaternion and ZYX Euler angles in degrees.
4. **Gravity removal** → dynamic acceleration magnitude → motion mask.
5. **Motion cancellation** (`motion_cancel()`) — an order-8 per-axis
   least-squares (Wiener) regression that subtracts the accelerometer reference
   out of the PPG.
6. **Spectral BPM** (`spectral_bpm()`) — sliding 8 s window, 2 s step, FFT.
7. **Beat detection** (`compute_beats()`) → IBI, instantaneous BPM, RMSSD, SpO2.

Numbered as a list it reads linear, but the real shape branches: the PPG is
filtered **twice**, into two different bands for two different consumers, and the
DC levels bypass both.

```mermaid
flowchart LR
  RAW["red / ir<br/>raw counts"]
  ACC["ax ay az<br/>gx gy gz"]

  RAW --> DISP["display band<br/>0.5–8 Hz"]
  RAW --> DC["ir_dc / red_dc<br/>DC levels"]
  ACC --> AHRS["Madgwick AHRS<br/>+ gravity removal"]
  AHRS --> MREF["motion reference<br/>≤ 3.5 Hz"]
  AHRS --> MMASK["motion mask<br/>0.5 × rolling RMS, 4 s"]
  DC --> CMASK["contact mask<br/>ir_dc ≥ 5000"]

  RAW --> MC["motion_cancel()<br/>order-8 Wiener"]
  MREF --> MC
  MC --> BEAT["beat band<br/>0.7–3.0 Hz"]

  BEAT --> CB["compute_beats()<br/>IBI, BPM, RMSSD"]
  BEAT --> SB["spectral_bpm()<br/>8 s window, 2 s step, SNR ≥ 2.0"]
  DC --> SPO2["SpO2 · 110 − 25·R"]
  CMASK -.-> CB
  CMASK -.-> SB
  MMASK -.-> CB

  DISP --> E[("_enriched.csv<br/>per sample")]
  CB --> B[("_beats.csv<br/>per beat")]
  SPO2 --> B
  AHRS --> E
  SB --> S[("_bpm_spectral.csv<br/>per 2 s window")]
```

### Why the parameters are what they are

The code comments carry most of this; the non-obvious choices:

**Two different PPG bands.** The display band is 0.5–8 Hz — 8 Hz preserves up to
the 6th harmonic at 80 BPM (1.33 Hz × 6), which is what gives a realistic pulse
*shape*. But those same harmonics plus the dicrotic notch create secondary peaks
that make `find_peaks` double-count beats. So beat detection uses a narrower
**0.7–3.0 Hz** (42–180 BPM) fundamental-only band, giving one clean peak per
cardiac cycle.

**Motion reference is band-limited to 3.5 Hz** so the regression removes motion
without eating cardiac harmonics.

**Adaptive peak height** — peaks must exceed 0.5 × rolling RMS over a 4 s window,
which handles contact quality drifting during a recording better than a fixed
threshold.

**IBI outlier rejection** — median filter over 5 beats, rejecting anything
±30 % off.

**Spectral BPM penalises motion** by scoring `ppg − 0.5 × accel` spectra, and
skips any window below `SPECTRAL_SNR_MIN = 2.0` or with under 50 % contact.

**No-contact data is dropped, not flagged.** Beats and spectral windows during
periods without skin contact are discarded entirely — an unworn sensor has no
physiological signal worth reporting.

**SpO2** uses the Mendelson ratio model, `110 − 25·R`. This is an uncalibrated
literature model on an uncalibrated sensor; treat the numbers as relative trends,
not clinical values.

---

## 3. `analysis/explore.py` — interactive viewer

A pyqtgraph viewer with linked pan/zoom across all signals. Point it at the
original logger CSV and it auto-discovers the `_enriched` and `_beats` siblings.

```bash
make explore FILE=logs/2026-06-15_10-49-03.csv
```

Requires `pyqtgraph`, `PyQt6` and `PyOpenGL` (all in `requirements.txt`).

---

## Live vs offline: two different DSP paths

The bridge that feeds the desktop app does **not** run this pipeline. It computes
a lighter real-time subset:

| | Bridge (live) | Pipeline (offline) |
|---|---|---|
| Orientation | imufusion AHRS + ZUPT | Madgwick |
| Heart rate | 8 s FFT window, parabolic sub-bin interpolation, rate-limited smoothing | Peak detection + sliding spectral estimate |
| PPG filter | single-sample EMA band-pass | 4th-order Butterworth, zero-phase |
| Motion cancellation | none | order-8 Wiener regression |
| SpO2 / HRV | not computed | computed |

The live path is deliberately cheap and causal; the offline path is zero-phase
and can look at the whole recording. Expect their BPM estimates to differ
slightly — the offline one is the reference.

### Yaw drift

There is no magnetometer on this board, so absolute heading is unobservable and
yaw drifts. The live bridge applies **ZUPT** (zero-velocity update): when
‖gyro‖ < 0.05 rad/s for 20 consecutive samples it zeroes the gyro input, which
suppresses drift while the node is still. This mitigates but does not eliminate
the problem. Roll and pitch are gravity-referenced and stay accurate.

---

## ⚠️ Known caveat: the app's CSVs are not pipeline input

`pipeline.py` calls `pd.read_csv(path).astype(float)` and expects the **logger**
schema (`timestamp,red,ir,ax…gz`, float timestamp).

Sessions recorded by the desktop app use a different schema — ISO-8601 string
timestamps, `ppg_red`/`ppg_ir` instead of `red`/`ir`, plus quaternion and BPM
columns. Feeding one to `make process` raises on the timestamp conversion.

**There is no converter in the repo yet.** For now, use `make log` when you
intend to run the offline pipeline, and the app's recorder when you want
multi-node sessions. See [roadmap.md](roadmap.md).

There is now a **third** format this pipeline cannot read: the hub's on-card
`.BIN` files (512-byte header, 16-byte records, documented in
[firmware-hub.md](firmware-hub.md#file-format)). The app can download them, but
nothing here parses them, so a downloaded session is currently a raw deliverable
rather than an input.

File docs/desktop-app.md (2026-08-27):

# Desktop App

`app/` is an Electron application that acquires from several PhysDAQ nodes at
once, plots them live, and records synchronised CSV sessions.

**Stack:** electron-vite 5 · Electron 39 · React 19 · TypeScript 5.9 ·
Tailwind v4 · shadcn/ui (new-york, Radix) · three.js · lucide-react.

It does **not** talk to hardware itself. All serial and BLE I/O happens in
`scripts/bridge.py`, which the main process spawns as a child — see
[protocol.md](protocol.md) for the JSON it emits.

---

## Process architecture

```mermaid
flowchart TB
  subgraph MAIN["Electron main process"]
    direction TB
    IDX["index.ts<br/>window, app lifecycle, IPC wiring"]
    SC["sidecar.ts<br/>one bridge child per connected device"]
    FL["flasher.ts<br/>UF2 copy to the bootloader drive"]
    CFG["config.ts<br/>nodes.json — persisted aliases"]
  end

  PRE["preload/index.ts · contextBridge<br/>window.api — typed as SidecarAPI"]
  REN["Renderer · React<br/>App.tsx holds all state<br/>samples coalesced per animation frame"]

  BR["bridge (long-lived)<br/>one process per device"]
  Q["bridge (one-shot)<br/>--list-ports / --scan / --scan-all<br/>execFile, exits immediately"]
  DEV(["Device — serial or BLE"])
  CSV[("session CSVs")]
  UF2[("XIAO-SENSE<br/>bootloader drive")]

  SC -- "spawn" --> BR
  BR -- "stdout: JSON<br/>stderr: text" --> SC
  SC -- "stdin: JSON commands<br/>EOF ⇒ bridge exits" --> BR
  BR <--> DEV
  SC -.-> Q
  SC --> CSV
  FL --> UF2

  MAIN -- "sensor-data · sensor-status<br/>sidecar-log · flash-progress" --> PRE
  PRE --> REN
  REN -- "invoke / send" --> PRE
  PRE --> MAIN
```

The one-shot query path is a different lifecycle from the per-device spawn: it
runs the same binary, prints one JSON array, and exits. Only the long-lived
processes are tracked.

One child process **per device**, tracked in
`activeSensors: Map<id, {process, mode, target, position, deviceType, channelSlots}>`.
A hub is one process feeding two body positions — see *Two slots per hub* below.

### How the bridge is located

`getBridgeInvocation()` in `sidecar.ts`:

| Build | Invocation |
|---|---|
| Development | `<repo>/.venv/Scripts/python.exe scripts/bridge.py` (or `.venv/bin/python`; falls back to bare `python` on PATH if neither venv exists) |
| Packaged | `<process.resourcesPath>/bridge/bridge[.exe]` — the PyInstaller bundle |

`getRepoRoot()` finds the repo by walking up from `app.getAppPath()` looking for
`scripts/bridge.py`, so the checkout can live anywhere and be named anything.

If the packaged binary is missing, the error names the expected path and tells
you to run `npm run build:sidecar` — a silent failure here is very hard to
diagnose otherwise.

### PYTHONPATH is stripped deliberately

`getPythonEnv()` removes `PYTHONPATH` and `PYTHONHOME` from the child's
environment. The Zephyr toolchain setup script (`scripts/setup-env.ps1`) points
both at the Nordic toolchain's Python, which breaks numpy's C extensions in the
venv. If you launch the app from a shell where you have sourced the Zephyr env,
this is what keeps it working.

---

## IPC surface

Exposed to the renderer as `window.api` through `contextBridge`; typed as
`SidecarAPI` in `app/src/preload/index.d.ts`.

| Channel | Kind | Payload → Result |
|---|---|---|
| `get-serial-ports` | `handle` | → `[{port, desc, hwid}]` |
| `scan-ble` | `handle` | `all?: boolean` → `[{address, name, rssi, deviceType, ppgCount, hasSd}]` — `scanBle()` renames the bridge's snake_case keys (see [protocol.md](protocol.md#bridge-invocation)); this is the only place the two conventions meet |
| `connect-sensor` | `on` | `{id, mode: 'serial'\|'ble', target, position, deviceType?, channelSlots?}` |
| `disconnect-sensor` | `on` | `id` |
| `disconnect-all` | `on` | — *(not exposed in preload; currently unreachable)* |
| `send-device-command` | `handle` | `(id, cmd)` → `{success, dest?, error?}` |
| `get-node-aliases` | `handle` | → `Record<target, alias>` |
| `set-node-alias` | `handle` | `(target, alias)` → updated map |
| `get-firmware-info` | `handle` | → `{node: FirmwareInfo, hub: FirmwareInfo}` |
| `get-bootloader-status` | `handle` | → `{present, drive?}` *(never called)* |
| `flash-node` | `handle` | `image: 'node'\|'hub'` → `{success, error?}` |
| `flash-progress` | `send` (M→R) | `{stage, message}` |
| `start-recording` | `handle` | `sessionName` → `{success, sessionPath?, error?}` |
| `stop-recording` | `handle` | → `{success, error?}` |
| `get-recordings` | `handle` | → session list |
| `get-recording-data` | `handle` | `(sessionPath, filename)` → `{success, data[]}` |
| `delete-recording` | `handle` | `sessionPath` → `{success}` |
| `sensor-data` | `send` (M→R) | one bridge JSON object + `sensorId`, `position`, `deviceId`, `deviceType`; sample messages also carry `channelIndex`, which is what drives the `HUB·S0` / `HUB·S1` markers |
| `sensor-status` | `send` (M→R) | `{sensorId, status, code?, error?}` |
| `sidecar-log` | `send` (M→R) | `{sensorId, log}` |
| `ping` | `on` | scaffold leftover, unused |

The four `on*` subscribers return unsubscribe closures.

### Device commands

`send-device-command` writes one JSON line to the bridge's stdin, which
translates it into the firmware's `CMD …` grammar. Replies come back as ordinary
`sensor-data` messages with their own `type`, so nothing in the main process has
to know about them — the stdout handler forwards any JSON object verbatim.

`sd.get` is the exception: the main process fills in the destination path
(`Documents/PhysDAQ_Sessions/hub_downloads/`) before forwarding, so the renderer
cannot choose where a file lands, and the bridge writes the megabytes to disk
directly rather than pumping them through IPC.

### Two slots per hub

`connect-sensor` takes `channelSlots`: one body-position slot per PPG channel.
A node passes one (its own id); a hub passes two. The stdout handler fans each
sample out per channel, flattening `ch[i]` to the top level so every slot
receives exactly the shape a single-PPG node would have produced.

That is what keeps everything downstream unchanged — charts, telemetry cards and
the 17-column session CSV all still see one PPG stream per slot.
`activeRecordings` is keyed on the **slot**, not the device, so a hub simply
writes two files. Device-level messages (battery, link status, SD and satellite
replies) go to both of a hub's slots, since both sit on one battery and one
link. `sidecar-log` fans out the same way: one bridge process has one stderr,
but each slot has its own System Logs pane, so both get every line.

End to end, one wire line becomes two CSV files:

```mermaid
flowchart LR
  LINE["<code>PPG red=… ir=… | PPG1 red=… ir=… | IMU ax=…</code><br/>one line, both sensors"]
  subgraph BRIDGE["bridge.py — one process"]
    direction TB
    P0["PpgChannel 0<br/>own ring buffer, BPM, baseline"]
    P1["PpgChannel 1<br/>own ring buffer, BPM, baseline"]
    AHRS["AHRS · quaternion<br/><b>shared — one IMU per board</b>"]
  end
  JSON["one <code>sample</code> JSON<br/>ch[0] duplicated at top level<br/>+ ch[] array"]
  subgraph FAN["sidecar.ts — emitToSlot"]
    direction TB
    S0["channelSlots[0]<br/>e.g. wrist_left"]
    S1["channelSlots[1]<br/>e.g. finger_left"]
  end
  C0[("wrist_left.csv")]
  C1[("finger_left.csv")]

  LINE --> P0 & P1 & AHRS
  P0 & P1 & AHRS --> JSON
  JSON --> S0 & S1
  S0 --> C0
  S1 --> C1
  JSON -. "battery, identity, hub_status,<br/>SD / REC / SAT replies —<br/>device-level, sent to both" .-> FAN
```

Channel fields are flattened to the top level before the fan-out, so each slot
receives exactly the shape a single-PPG node would have produced. That is what
keeps the 17-column session CSV unchanged.

A hub connected **without** a second slot is allowed: `channelSlots` then holds
one entry and channel 1 is discarded on the host. The sensor is still acquired
and still logged to the hub's own card — it simply is not charted or written to
a session CSV. The connect dialog warns about this.

---

## Flashing

`flash-node` copies a UF2 to the board's bootloader drive. Four things about it
are non-obvious:

- **The bridge is disconnected first**, with an 800 ms wait for the OS to release
  the serial port. A locked port fails the copy.
- **The image follows the Device Type selector**, not any autodetect — both
  images run on the same board, so nothing on the drive says which one belongs
  there.
- **The drive is found by polling** every drive letter / mount point for an
  `INFO_UF2.TXT` containing `XIAO`, up to a 60 s deadline. That is the window in
  which the user double-taps RST.
- **A write error after the volume disappears counts as success.** The bootloader
  unmounts the drive the moment it accepts the image; that unmount is the only
  completion signal there is. Still mounted after ten retries is the failure.

Image sources are `build/zephyr/zephyr.uf2` and `build-hub/zephyr/zephyr.uf2` in
development, `<resourcesPath>/firmware/physdaq.uf2` and `physdaq-hub.uf2` when
packaged.

---

## Session storage

Recordings are written to `Documents/PhysDAQ_Sessions/`, one folder per session,
one CSV **per slot** — so a hub occupying two body positions writes two files. Schema in [protocol.md](protocol.md#3-app--disk-session-csv).

`get-recordings` scans **two** base directories and merges the results:
`PhysDAQ_Sessions` and the pre-rename `MAID_Sessions`. The legacy directory is
listed but never written to, so sessions recorded before the rename remain
readable. Entries from it carry `legacy: true`. Every entry returns an absolute
`path`, which is why `get-recording-data` and `delete-recording` need no
knowledge of which directory a session came from.

Session metadata is derived by parsing the folder name (`session_<date>_<name>`)
and reading the **last line** of each CSV for an approximate duration — no index
file is maintained.

`get-recording-data` parses by header index, tolerating missing columns, and
**backfills `ppg_filt`** if it is absent by recomputing the same EMA band-pass the
bridge uses (`dc = dc*0.985 + ir*0.015; lp = lp*0.75 + (ir−dc)*0.25`). This keeps
older recordings displayable.

> There is currently no export feature — no save dialog, no format conversion.
> Data leaves the app as the raw CSV files already on disk. See [roadmap.md](roadmap.md).

---

## Renderer

`App.tsx` is a single component holding all state, with three pages selected by
`currentPage` (no router).

### Sensor model

A fixed 8-slot constant, `SENSOR_POSITIONS`, each with SVG coordinates on the
body map: `head`, `chest`, `wrist_left`, `wrist_right`, `finger_left`,
`finger_right`, `ankle_left`, `ankle_right`. All default to BLE except `chest`,
which defaults to serial.

Each `SensorNode` carries `{status, battery{pct,mv}, bpm, contact, quat, ax…gz,
logs[]}` plus `{deviceType, deviceId, channelIndex}`; logs are capped at 50
entries, newest first. The slot map is built from `SENSOR_POSITIONS` rather than
written out eight times — it used to be eight ~250-character literals, and every
new field meant editing all of them.

Two slots sharing a `deviceId` are the two halves of one hub: same IMU, same
battery, same link, different PPG sensor. The inventory marks them `HUB·S0` /
`HUB·S1`.

`hubs: Record<deviceId, HubState>` holds what belongs to the box rather than to
either position — card status, session file list, download progress, satellite
roster. Listings stream in entry by entry and are swapped into the visible list
only on their terminator, so a listing cut short by a disconnect cannot be
mistaken for an empty card.

### Pages

**Body Network** — session recording controls (name, Record/Stop, `mm:ss` timer)
and a node inventory on the left; on the right an SVG human wireframe with 8
positioned markers. Marker colour encodes state: emerald = connected and worn,
amber = connected but not worn, primary = connecting, muted = disconnected.

**Node Detail** — three live charts (filtered PPG, raw red/IR, gyro), a three.js
board visualiser driven by the AHRS quaternion, and cards for heart rate, wear
status, battery and raw telemetry, plus a System Logs pane fed from the bridge's
stderr.

**Session Database** — saved sessions on the left; on the right a per-sensor file
selector and a timeline scrubber (draggable viewport over a downsampled
`ppg_filt` sparkline, with zoom, pan and numeric range inputs). The selected
range is downsampled to ≤1000 points and rendered by the same chart component in
static mode.
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

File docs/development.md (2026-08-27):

# Development Guide

How to set up a machine, build every part of PhysDAQ, and package a release.

---

## Repository layout

```
firmware/           Zephyr application (C) — single-PPG node
  src/              acquisition loop, drivers, power management, BLE
  boards/           DeviceTree overlay for xiao_ble_sense
  dts/bindings/     custom MAX30102 binding
  Kconfig, prj.conf project configuration
firmware-hub/       Zephyr application (C) — dual-PPG + microSD hub
  src/              per-sensor threads, storage, command channel, self-test
  boards/           overlay: I2C mux, two PPG nodes, SPI SD slot
app/                Electron desktop application
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

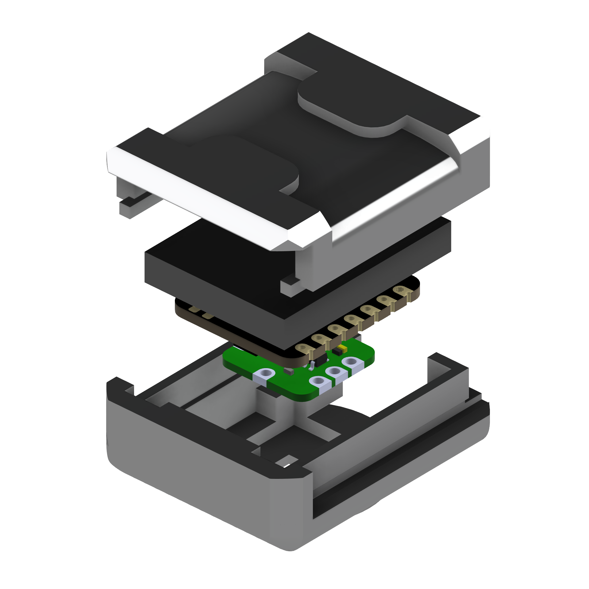
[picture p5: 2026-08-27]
assets/images/hardware/device-exploded-top.png

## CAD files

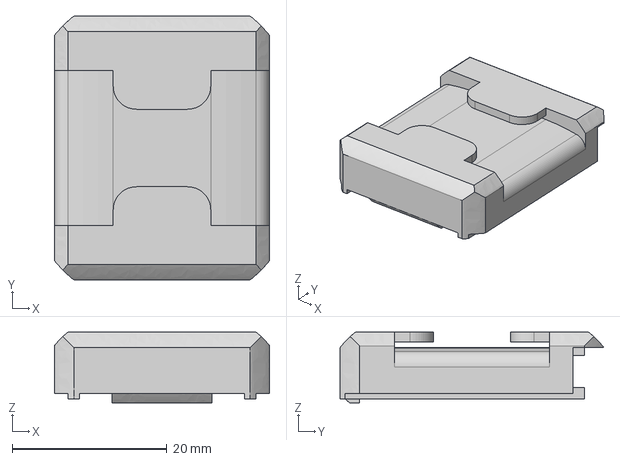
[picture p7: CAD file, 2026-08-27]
hardware/enclosure/models/physdaq-lid-v1.step
27.8 x 34.0 x 9.15 mm

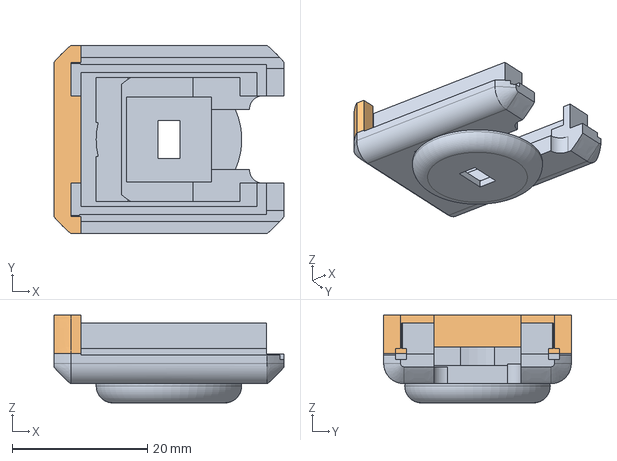
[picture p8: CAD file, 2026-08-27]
hardware/enclosure/models/physdaq-case-v1.step
34.0 x 27.8 x 13.0 mm

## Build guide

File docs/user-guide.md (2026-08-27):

# User Guide

How to prepare a PhysDAQ node, connect it to the desktop app, record a session,
and review the data afterwards.

This guide assumes the hardware is already assembled. For wiring, see
[hardware.md](hardware.md); for building from source, see
[development.md](development.md).

There are two kinds of device. A **node** carries one PPG sensor and occupies one
body position. A **hub** carries two PPG sensors, occupies two body positions from
a single connection, and records to its own microSD card as well as streaming.
Everything below applies to both unless it says otherwise.

```mermaid
flowchart TB
  A(["Assembled device"]) --> B{"Node or hub?"}
  B -- node --> C["Flash physdaq.uf2<br/>make build, or from the app"]
  B -- hub --> D["Flash physdaq-hub.uf2<br/>make hub, or from the app"]
  C & D --> E{"Transport?"}
  E -- "USB · 100 Hz" --> F["Full rate — use this<br/>when sample rate matters"]
  E -- "BLE · ~25 Hz" --> G["Untethered monitoring<br/>and live display"]
  F & G --> H{"Hub?"}
  H -- no --> I["Assign 1 body position"]
  H -- yes --> J["Assign 2 body positions"]
  I & J --> K["Wear · check contact turns emerald"]
  K --> L["Name the session · Record"]
  L --> M["Review in-app<br/>Session Database"]
  L --> N["Offline pipeline<br/>needs make log, not the app's CSV"]
```

---

## Installing the app

Download the file for your machine from the
[Releases page](https://github.com/haksolot/PhysDAQ/releases):

| Your machine | Download |
|---|---|
| Windows | `physdaq-<version>-setup.exe` |
| Mac (Apple Silicon) | `physdaq-<version>-arm64.dmg` |
| Linux | `physdaq-<version>-x86_64.AppImage`, or the `.deb` |

> The Windows build has been run and verified. The Mac and Linux builds package
> cleanly but have not yet been launched on real hardware — if something is
> wrong there, please open an issue.

The downloads are **not code-signed** — PhysDAQ is a lab instrument, not a
commercial product, and a signing certificate costs money the project does not
have. Your system will warn you the first time. This is expected:

- **Windows** — SmartScreen shows "Windows protected your PC". Click
  **More info** → **Run anyway**.
- **macOS** — the app is blocked on a double-click. **Right-click the app →
  Open**, then confirm. You only need to do this once.
- **Linux** — make the AppImage executable first: `chmod +x physdaq-*.AppImage`.
  To read a node over USB you also need to be in the `dialout` group
  (`sudo usermod -aG dialout $USER`, then log out and back in).

---

## 1. Prepare a node

### Flash the firmware

1. Connect the node over USB-C.
2. **Double-tap the RST button.** A mass-storage drive named `XIAO-SENSE`
   appears.
3. Copy the firmware onto it:

```bash
make flash
```

The board reboots by itself as soon as the copy finishes. If the drive is not
found, `make flash` prints the absolute path of the `.uf2` so you can drag it
across manually.

### Flashing from the desktop app

The installed app carries a firmware image, so you do not need a build toolchain
to set up a node:

1. Connect the device over USB.
2. Open a sensor slot's **Link** dialog, set **Device Type**, and press
   **Flash node firmware** or **Flash hub firmware**.
3. **Double-tap the RST button** when prompted. The app waits up to a minute for
   the `XIAO-SENSE` drive to appear, copies the image, and confirms.

The device reboots by itself. If it is already connected in the app, the flash
step disconnects it first — a serial port cannot be held open while the device
behind it is being flashed.

> **The Device Type selector decides which image is written**, and nothing checks
> it against the board. Both images run on the same hardware, so flashing node
> firmware onto a hub succeeds and silently gives you one sensor and no card.
> Confirm the selector before flashing.

If you built the app from source, it flashes whatever you last compiled —
`make build` for a node, `make hub` for a hub — and the button is disabled until
the matching image exists.

### Check that it works

```bash
make term
```

You should see the boot banner followed by a stream of sample lines:

```
ID model=node proto=2 fw=1.2.0 ppg=1 sd=0 name=PhysDAQ-FDF9
=== PhysDAQ: PPG + IMU acquisition ===
PPG: SpO2 mode, 100 Hz, 18-bit ADC
IMU: accel [m/s^2], gyro [rad/s]
BLE: NUS advertising as PhysDAQ
Battery: VBAT via P0.31/AIN7, sampled every 5 s
Power: sleep after 10 s idle
...
PPG red=28451 ir=29033 | IMU ax=0.213 ay=-9.706 az=0.884 gx=0.001 gy=-0.004 gz=0.002
Battery: 71% (3940 mV)
```

The first line is the device identifying itself — `model=node` or `model=hub`,
and `ppg=` how many sensors it carries. It is the quickest way to confirm you
flashed the image you meant to.

With nothing touching the sensor, `ir` reads a few hundred. Place a fingertip on
the PPG window and it jumps to ~29 000 — that is the contact threshold the whole
system uses.

Press `Ctrl+]` then `q` to quit the terminal.

---

## 2. Wearing and placement

- The PPG window must sit **flat against skin** with light, steady pressure. Too
  loose and the signal drops out; too tight and you restrict perfusion and lose
  the pulse.
- Fingertip, wrist (over the radial artery) and earlobe give the strongest
  signals. Torso and ankle placements are usable but noisier.
- Keep the node **still** during a measurement window. Motion is the dominant
  artefact source; the offline pipeline can regress much of it out, but clean
  data is always better.
- Give it 10–20 s to settle after placement before starting a recording.

---

## 3. Connect nodes in the app

Launch PhysDAQ (installed build, or `npm run dev` from `app/`).

On the **Body Network** page, click any of the eight body positions — head,
chest, wrist ×2, finger ×2, ankle ×2 — to open the *Configure Sensor Node*
dialog.

1. Choose the transport: **USB Serial** or **BLE NUS**. The dialog scans
   automatically on open and whenever you switch transport. Positions default to
   BLE, except *chest*, which defaults to USB.
2. Pick the discovered port or device from the list, or leave it on
   *auto-detect*. A manual override field is there if a device does not appear,
   and **Show all BLE devices** drops the PhysDAQ filter if a node advertises
   without its service UUID. Hubs are badged **HUB** in the list.
3. Set **Device Type** — `Node · 1 PPG` or `Hub · 2 PPG + SD`. A hub advertises
   its type, so this is usually pre-selected; set it by hand for a device
   connected over USB or running older firmware. It also decides which firmware
   image the Flash button writes.
4. For a hub, pick a **Second PPG Position**. The hub then occupies two body
   positions from one connection and writes two CSVs. Leaving it unset is
   allowed — the second sensor is still acquired and still logged to the hub's
   card, but it is not charted and not written to a session CSV.
5. Optionally give the device a **Node Name**; it is remembered across sessions.
6. Confirm. The marker turns amber (connected, not worn) and then emerald once
   skin contact is detected.

Repeat for each device. There are eight body positions in total, and a hub
consumes two of them — so four hubs fill the map. Each connection is an
independent process.

A hub's two positions are badged **HUB·S0** and **HUB·S1** in the inventory.
They share one battery, one radio link and one IMU, so orientation, battery and
link status are identical on both; only the PPG differs.

**Marker colours**

| Colour | Meaning |
|---|---|
| Emerald | Connected and worn |
| Amber | Connected, no skin contact |
| Primary (purple) | Connecting |
| Muted (grey) | Disconnected |

> Over BLE the app receives ~25 Hz rather than the full 100 Hz — a deliberate
> rate limit, since a BLE link cannot sustain the full stream. **Use USB for
> anything where sample rate matters.** BLE is for untethered monitoring and
> live display.

---

## 4. Live monitoring

Click a connected node's **Detail** button for:

- **PPG Filtered** — the pulse waveform. This is what you look at to judge signal
  quality; a clean trace shows a clear repeating pulse with a visible dicrotic
  notch.
- **PPG Raw** — red and IR channels at 18-bit. Useful for checking contact and
  saturation.
- **IMU gyro** — angular rate on all three axes.
- **3D board orientation** — live attitude from the fusion filter.
- Cards for heart rate, wear status, battery, and raw telemetry.
- **System Logs** — everything the device printed that wasn't a data sample,
  including battery, power state and any sensor re-initialisation.

Heart rate needs about 8 s of contact before the first value appears — it comes
from a sliding spectral window, not from single beats. It shows `--` when there
is no contact or no confident estimate.

---

## 5. Record a session

1. On the **Body Network** page, enter a session name.
2. Press **Record**. A `mm:ss` timer starts.
3. Press **Stop** when finished.

All currently connected devices are recorded, sharing a common session start
time. There is one CSV **per body position**, not per device — so a hub occupying
two positions writes two files, one per sensor.

**Where files go:**

```
Documents/PhysDAQ_Sessions/session_<date>_<name>/
    chest.csv
    wrist_left.csv
    ...
```

Only devices connected **at the moment you press Record** are included —
connecting another one mid-session does not add it. Stop and restart if you need
to change the set.

This is the app's own recording, on the host. A hub can *also* record to its own
card at the same time, started separately from the Hub Storage panel; the two are
independent.

Columns are documented in [protocol.md](protocol.md#3-app--disk-session-csv).

---

## 6. Review recordings

The **Session Database** page lists every saved session with its date, duration
and node count.

> A `hub_downloads` folder sits alongside the sessions — it holds raw `.BIN`
> files pulled off a hub's card, and is skipped by this list.

Select a session, then a node's CSV, to load it into the timeline scrubber:

- Drag or click the viewport box on the sparkline to pan.
- **Zoom In / Zoom Out**, **Scroll Left / Right**, **Reset View**.
- Type exact start/end percentages for a precise window.

The selected range is rendered in the same three charts used for live view. Time
labels along the scrubber are wall-clock times from the recording.

The trash icon on a session row deletes the whole folder from disk — this is
immediate and not undoable.

> Sessions recorded before the project was renamed from MAID still appear here.
> They are read from `Documents/MAID_Sessions` and remain fully usable; new
> recordings always go to `PhysDAQ_Sessions`.

---

## Working with a hub

A hub's Node Detail page carries two extra panels. Both are reachable from either
of its two body positions — they act on the device, not the slot.

### Hub Storage

Shows the card's used and total space, whether a session is currently open, and
the running counters for records written, dropped and errored. `dropped` should
be zero; anything else means the card could not keep up.

- **New session** starts a recording on the card, **Stop session** ends it. This
  is the hub's own recording and is independent of the app's Record button — you
  can run either, both, or neither.
- Each file on the card can be **downloaded** or deleted. Downloads land in
  `Documents/PhysDAQ_Sessions/hub_downloads/`.
- **Erase card** removes every session file. It requires typing `ERASE` to
  confirm, and it deliberately does *not* reformat — anything the firmware did
  not write is left untouched.

> **Downloads share the radio link with the live stream.** A one-hour session is
> roughly 11 MB, which is about 50 minutes over BLE and 20 over USB. The panel
> shows an estimate before you start. Prefer USB, and expect the live view to
> slow down during a transfer.

> **Nothing in this project reads a downloaded `.BIN` yet.** The files are a raw
> deliverable for now — the offline pipeline cannot open them. See
> [roadmap.md](roadmap.md).

### Satellites

A hub remembers a roster of up to eight other nodes, each with an address and a
short label.

> **This is configuration only.** The hub does not scan for these nodes, connect
> to them, or record anything from them — the roster is remembered for a future
> capability that is **not implemented**. Adding an entry changes nothing about
> what gets captured today. The panel says so permanently, and it is worth
> repeating: if you want a second node's data, connect it to the app as its own
> device.

### Sleep

A hub does **not** deep-sleep — the feature is compiled out. The idle timeout and
wake-on-motion behaviour described under *Battery and sleep* below applies to
single-PPG nodes only. A hub stays awake until it loses power.

---

## 7. Offline analysis

The app is for acquisition and quick review. For beat detection, HRV, SpO2 and
motion cancellation, use the Python pipeline:

```bash
make log                              # record via the standalone logger
make process FILE=logs/<file>.csv     # → *_enriched.csv, *_beats.csv
make explore FILE=logs/<file>.csv     # interactive viewer
```

> ⚠️ The offline pipeline currently reads the **logger's** CSV format, not the
> app's. Use `make log` for recordings you intend to process offline. Details and
> workaround status in [analysis.md](analysis.md).

---

## Battery and sleep

> This section describes the **single-PPG node**. A hub has deep sleep disabled
> and never enters it.

A node reports its charge every 5 s; the app shows it on the node's detail page.

After `CONFIG_PHYSDAQ_IDLE_TIMEOUT_SEC` seconds (default 10) with **no motion and
no skin contact**, the node enters deep sleep at ~0.4 µA. Wearing it while sitting
perfectly still does *not* put it to sleep — only setting it down does.

**Waking it:** pick it up or move it. The node performs a full reset, so:

- its USB serial port disappears and comes back as a new one;
- the app shows the node as disconnected and you must reconnect it.

To change the timeout, edit `firmware/prj.conf` and reflash:

```
CONFIG_PHYSDAQ_IDLE_TIMEOUT_SEC=30    # range 5–300
```

```bash
make rebuild && make flash
```

---

## Troubleshooting

| Symptom | Likely cause | Fix |
|---|---|---|
| No devices in the BLE scan | Node asleep, or already connected elsewhere | Move the node to wake it; a node accepts one connection at a time |
| Node connects then drops immediately | Another process holds the serial port | Close `make term` / the live plotter first |
| Flat or noisy PPG trace | Poor skin contact | Reseat the sensor; steady, light pressure |
| BPM stays `--` | No contact, or too much motion | Check wear status shows WORN; hold still 10 s |
| Wear status says worn with nothing on it | A reflective surface at the right distance reads like skin | Known limitation of DC-only contact detection |
| Orientation drifts in yaw | No magnetometer on this board | Expected; roll and pitch stay accurate |
| Serial port vanished mid-session | Node went to sleep | Wake it and reconnect |
| App says "Python sidecar not found" | Development build without the frozen bridge | See [development.md](development.md#packaging-the-desktop-app) |

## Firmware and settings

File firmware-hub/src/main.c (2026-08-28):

#include <zephyr/kernel.h>
#include <zephyr/sys/printk.h>
#include <zephyr/drivers/sensor.h>
#include "imu.h"
#include "ppg.h"
#include "storage.h"
#include "power.h"
#include "ble.h"
#include "battery.h"
#include "contact.h"
#include "watchdog.h"
#include "selftest.h"
#include "version.h"
#include "command.h"
#include "satellites.h"
#include "crashlog.h"

/* Format a sensor_value (val1 + val2/1e6) as "±integer.milli" using printk.
 * Mirrors the print_val helper in imu.c, kept local to avoid coupling. */
#define SV_SIGN(v)  (((v)->val1 < 0 || (v)->val2 < 0) ? "-" : "")
#define SV_INT(v)   ((v)->val1 < 0 ? -(v)->val1 : (v)->val1)
#define SV_MILLI(v) (((v)->val2 < 0 ? -(v)->val2 : (v)->val2) / 1000)

/* Supervisor cadence. Acquisition and storage run on their own threads now, so
 * this loop only has to service the things that are inherently periodic: the
 * watchdog, the IMU, the BLE stream and the status lines. 40 ms lands it on
 * the same ~25 Hz the BLE link is rate-limited to. */
#define SUPERVISOR_PERIOD_MS  40
#define HUB_STATUS_INTERVAL_MS  5000

/* How often to re-run the bus diagnostics while nothing is acquiring.
 *
 * The console is a USB CDC ACM port, so it does not exist yet while the board
 * is booting — by the time a terminal can attach, the boot output is long
 * gone. That makes a once-at-boot diagnostic useless in exactly the situation
 * it was written for. Repeating it while the board is broken means you can
 * attach whenever and still get the verdict. */
#define DIAG_INTERVAL_MS  10000

/* Set once acquisition threads are running — used only for the uptime display. */
static int64_t acq_start_ms;

/*
 * Per-sensor rate in tenths of a hertz, measured over the last status interval
 * rather than since acquisition began.
 *
 * A since-start average is contaminated by a fixed head start: each sensor's
 * 32-deep FIFO is already filling while the *other* sensor's init runs, and a
 * failing init burns hundreds of milliseconds of retries. That showed up as a
 * rate reading a few percent high and slowly decaying, which looks exactly
 * like a real drift and is not one. A windowed rate has no such offset, and it
 * also surfaces a sensor that degrades mid-session — which a since-start
 * average would bury under all the healthy minutes before it.
 *
 * This is the number that says whether a sensor runs at the configured ODR.
 * "It produces samples" is not "it produces them at 100 Hz", and a low rate is
 * sample loss even when the overflow counter is clean.
 */
static uint32_t windowed_dhz(uint8_t idx, uint32_t samples, int64_t now_ms)
{
	static uint32_t prev_samples[PPG_SENSOR_COUNT];
	static int64_t  prev_ms[PPG_SENSOR_COUNT];

	if (idx >= PPG_SENSOR_COUNT) {
		return 0;
	}

	int64_t  dt = now_ms - prev_ms[idx];
	uint32_t dn = samples - prev_samples[idx];   /* wraps correctly */

	prev_samples[idx] = samples;
	prev_ms[idx]      = now_ms;

	if (dt < 1000) {
		return 0;   /* window too short to mean anything */
	}
	return (uint32_t)(((uint64_t)dn * 10000) / (uint64_t)dt);
}

static void send_hub_status(void)
{
	struct ppg_live      s0, s1;
	struct storage_stats st;

	ppg_get_live(0, &s0);
	ppg_get_live(1, &s1);
	storage_get_stats(&st);

	int64_t  now_ms = k_uptime_get();
	uint32_t d0 = windowed_dhz(0, s0.samples, now_ms);
	uint32_t d1 = windowed_dhz(1, s1.samples, now_ms);
	uint32_t up_s = (uint32_t)((now_ms - acq_start_ms) / 1000);

	/* Deliberately does NOT start with "PPG". bridge.py matches the sample
	 * line with re.search(r'PPG\s+red=...') and silently discards any other
	 * line beginning with those three characters, so a status line prefixed
	 * "PPG..." would vanish without trace. The same rule governs every
	 * reply in command.c. */
	/* 256, not 224: `open=` and `sat=n/N` were added after the original
	 * sizing and the line was already close to full. */
	char line[256];
	int n = snprintk(line, sizeof(line),
		"Hub: up=%us | s0 %s n=%u %u.%uHz ovf=%u ri=%u ir=%u | "
		"s1 %s n=%u %u.%uHz ovf=%u ri=%u ir=%u | "
		"sd sess=%u open=%u w=%u drop=%u sync=%u err=%u qmax=%u "
		"sat=%u/%u\n",
		up_s,
		s0.alive ? "ok" : "DEAD", s0.samples, d0 / 10, d0 % 10,
		s0.overflows, s0.reinits, s0.ir,
		s1.alive ? "ok" : "DEAD", s1.samples, d1 / 10, d1 % 10,
		s1.overflows, s1.reinits, s1.ir,
		st.session_id, storage_session_is_open() ? 1U : 0U,
		st.records_written, st.records_dropped,
		st.syncs, st.write_errors, st.max_queue_used,
		satellites_count(), SATELLITES_MAX);

	printk("%s", line);
	ble_send((const uint8_t *)line, n);
}

int main(void)
{
	/* Before anything else: captures the previous boot's crash/hang record
	 * and the reset cause while nothing has had a chance to clobber them. */
	crashlog_init();

	/* Bus self-test first, before anything that depends on the bus. On a
	 * hand-wired prototype the difference between "the mux is missing" and
	 * "the sensor behind the mux is missing" is the difference between two
	 * completely different repairs, and an -EIO out of max30102_init()
	 * cannot tell them apart. */
	selftest_run();

	if (imu_init() < 0) {
		printk("IMU init failed — continuing without motion data\n");
	}

	/* Storage first: it anchors the session clock, and the acquisition
	 * threads read that epoch once when they start. Starting them earlier
	 * would date every record against an epoch of zero. */
	bool logging = (storage_init() == 0);

	if (!logging) {
		printk("Storage init failed — acquisition will run but NOTHING "
		       "WILL BE RECORDED. Check the card and reboot.\n");
	}

	bool acquiring = (ppg_init() == 0);

	acq_start_ms = k_uptime_get();

	if (!acquiring) {
		/* Deliberately not a halt. The single-PPG firmware returned
		 * here, which kills the console output too — on a prototype
		 * being wired up, staying alive so the self-test result and the
		 * periodic status line stay readable is worth far more than
		 * exiting cleanly. */
		printk("No PPG sensor available — staying up so the self-test "
		       "output above remains readable. Fix the wiring and "
		       "reset.\n");
	}

	if (battery_init() < 0) {
		printk("Battery ADC init failed — continuing without battery "
		       "status\n");
	}

	contact_init();
	power_init();

	if (ble_init() < 0) {
		printk("BLE init failed — running USB-only\n");
	}

	/* Roster before the command thread, so a "sat.list" arriving in the
	 * first milliseconds answers with what is actually stored rather than
	 * with an empty list. A failure here is not fatal: the roster still
	 * works for this boot, it just will not survive a reset. */
	if (satellites_init() < 0) {
		printk("Satellites: roster will not persist across reboots\n");
	}

	command_init();

	/* Arm the watchdog only after all (potentially slow) init has finished,
	 * so init delays can never trip it. From here on, this loop must feed
	 * it. Note the scope change from the single-PPG firmware: the watchdog
	 * now guards the supervisor, not acquisition. A wedged sensor is
	 * handled by the per-sensor stall recovery in ppg.c, which is the right
	 * place for it — resetting the whole SoC would close the session file. */
	watchdog_init();

	printk("\n=== PhysDAQ Hub: dual PPG + microSD ===\n");
	/* Mux channels 1 and 2, which the breakout silk-screens "2" and "3".
	 * The banner used the silk-screen numbers; every other message and all
	 * of the docs use the channel indices, so it read as a third pair. */
	printk("PPG: 2× MAX30102 behind PCA9546A ch1/ch2, SpO2 %d Hz, 18-bit\n",
	       CONFIG_PHYSDAQ_PPG_ODR_HZ);
	printk("IMU: accel [m/s^2], gyro [rad/s]\n");
	printk("Time base: k_uptime_ticks() @ %d Hz (%d us), captured in ISR\n",
	       CONFIG_SYS_CLOCK_TICKS_PER_SEC,
	       1000000 / CONFIG_SYS_CLOCK_TICKS_PER_SEC);
	printk("Storage: %s\n", logging ? "active" : "UNAVAILABLE");
	printk("BLE: NUS advertising\n");
	printk("Deep sleep: %s\n",
	       IS_ENABLED(CONFIG_PHYSDAQ_DEEP_SLEEP) ? "enabled" : "disabled");
	printk("\n");

	command_send_identity();

	int64_t last_status_ms = k_uptime_get();
	int64_t last_diag_ms   = k_uptime_get();

	while (1) {
		/* Feed the watchdog once per iteration. The loop turns over
		 * every SUPERVISOR_PERIOD_MS, so if anything below hangs the
		 * feeds stop and the SoC resets itself within the WDT window
		 * instead of freezing indefinitely. */
		watchdog_feed();

		/* Rising edge of the BLE link: a central that just connected
		 * has not seen the boot copy of the identity line. */
		static bool was_linked;
		bool linked = ble_is_connected();
		if (linked && !was_linked) {
			command_send_identity();
		}
		was_linked = linked;

		struct imu_sample imu;
		bool have_imu = (imu_fetch_sample(&imu) == 0);

		struct ppg_live s0, s1;
		ppg_get_live(0, &s0);
		ppg_get_live(1, &s1);

		if (have_imu) {
			/* The single-PPG line format, extended with a
			 * "| PPG1 red=… ir=…" section for sensor 1.
			 *
			 * Deliberately one line, not two. bridge.py matches the
			 * sample with re.search(r'PPG\s+red=…'), so this
			 * still matches on sensor 0 and an un-updated bridge
			 * keeps working — while a *separate* line beginning
			 * "PPG1" would be silently discarded by the same code
			 * path, which drops any unmatched line starting with
			 * "PPG". Keeping both sensors in one message also gives
			 * the pair a single arrival timestamp, so the host
			 * cannot desynchronise the two channels.
			 *
			 * 192 bytes, not 160: the PPG1 section adds up to ~28 B
			 * and the old buffer left no room for it. */
			char line[192];
			int n = snprintk(line, sizeof(line),
				"PPG red=%u ir=%u | PPG1 red=%u ir=%u | IMU "
				"ax=%s%d.%03d ay=%s%d.%03d az=%s%d.%03d "
				"gx=%s%d.%03d gy=%s%d.%03d gz=%s%d.%03d\n",
				s0.red, s0.ir, s1.red, s1.ir,
				SV_SIGN(&imu.accel[0]), SV_INT(&imu.accel[0]), SV_MILLI(&imu.accel[0]),
				SV_SIGN(&imu.accel[1]), SV_INT(&imu.accel[1]), SV_MILLI(&imu.accel[1]),
				SV_SIGN(&imu.accel[2]), SV_INT(&imu.accel[2]), SV_MILLI(&imu.accel[2]),
				SV_SIGN(&imu.gyro[0]),  SV_INT(&imu.gyro[0]),  SV_MILLI(&imu.gyro[0]),
				SV_SIGN(&imu.gyro[1]),  SV_INT(&imu.gyro[1]),  SV_MILLI(&imu.gyro[1]),
				SV_SIGN(&imu.gyro[2]),  SV_INT(&imu.gyro[2]),  SV_MILLI(&imu.gyro[2]));

			/* One notification per loop, i.e. ~25 Hz. The link
			 * carries ~4 kB/s; the raw 100 Hz × 2 sensor stream
			 * would be several times that and would overflow the TX
			 * queue. The SD file is the record of truth — BLE is
			 * only a live view. */
			ble_send((const uint8_t *)line, n);

			contact_update(s0.ir);
			power_update(imu.gyro);
		}

		/* Internally rate-limited to once every 5 s — cheap to call
		 * every iteration. */
		uint8_t batt_pct;
		int32_t batt_mv;
		if (battery_poll(&batt_pct, &batt_mv) == 0) {
			char batt_line[48];
			int batt_n = snprintk(batt_line, sizeof(batt_line),
				"Battery: %u%% (%d mV)\n", batt_pct, batt_mv);
			printk("%s", batt_line);
			ble_send((const uint8_t *)batt_line, batt_n);
		}

		int64_t now = k_uptime_get();
		if (now - last_status_ms >= HUB_STATUS_INTERVAL_MS) {
			last_status_ms = now;
			send_hub_status();
		}

		/* While nothing is acquiring, keep re-running the diagnostics
		 * so they are readable whenever a terminal attaches.
		 *
		 * Gated strictly on `acquiring`, which is false only when
		 * ppg_init() started no threads at all. That matters: the
		 * self-test writes the mux control register directly, behind
		 * the tca954x driver's back, and doing that while an
		 * acquisition thread is mid-transfer would corrupt it. With no
		 * threads running, the bus is ours alone. */
		if (!acquiring && now - last_diag_ms >= DIAG_INTERVAL_MS) {
			last_diag_ms = now;

			if (!logging) {
				printk("\nStorage: still unavailable "
				       "(last error %d)\n",
				       storage_last_error());
			}
			selftest_run();
		}

		k_sleep(K_MSEC(SUPERVISOR_PERIOD_MS));
	}

	return 0;
}

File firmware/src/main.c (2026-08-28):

#include <zephyr/kernel.h>
#include <zephyr/sys/printk.h>
#include <zephyr/drivers/sensor.h>
#include "imu.h"
#include "max30102.h"
#include "power.h"
#include "ble.h"
#include "battery.h"
#include "contact.h"
#include "watchdog.h"
#include "version.h"
#include "crashlog.h"
#include <zephyr/drivers/hwinfo.h>

/* Format a sensor_value (val1 + val2/1e6) as "±integer.milli" using printk.
 * Mirrors the print_val helper in imu.c, kept local to avoid coupling. */
#define SV_SIGN(v)  (((v)->val1 < 0 || (v)->val2 < 0) ? "-" : "")
#define SV_INT(v)   ((v)->val1 < 0 ? -(v)->val1 : (v)->val1)
#define SV_MILLI(v) (((v)->val2 < 0 ? -(v)->val2 : (v)->val2) / 1000)

/*
 * Identity line. This is what tells the host which firmware it is talking to
 * and how many PPG channels to expect.
 *
 * Sent over both transports, unlike most diagnostics. The manufacturer data in
 * the advertisement carries the same device type, but USB CDC has no
 * advertising at all, so without this line a cabled node is unidentifiable.
 * Re-sent on every new BLE connection: a central that connects late has missed
 * the boot copy, and on USB the console does not exist yet while the board
 * boots, so the boot copy is routinely lost there too.
 */
/* Why the SoC last started. Read once at boot and cleared, then repeated to
 * every host that connects: a node that keeps "disconnecting" over BLE may
 * in fact be rebooting, and this is the only way to tell a watchdog reset
 * (main loop hung) from a fatal error (crash) or wake-from-System-Off
 * without a cable on the console. */
static uint32_t boot_cause;
static int64_t  boot_ms;

static const char *boot_cause_str(uint32_t c)
{
    if (c & RESET_WATCHDOG)      return "watchdog";
    if (c & RESET_SOFTWARE)      return "software (fatal error or reboot)";
    if (c & RESET_LOW_POWER_WAKE) return "wake from deep sleep";
    if (c & RESET_PIN)           return "reset pin";
    if (c & RESET_POR)           return "power-on";
    if (c & RESET_BROWNOUT)      return "brownout";
    if (c & RESET_DEBUG)         return "debugger";
    return "unknown";
}

static void send_identity(void)
{
    char line[128];
    int n = snprintk(line, sizeof(line),
        "ID model=node proto=%d fw=%s ppg=1 sd=0 name=%s\n",
        PHYSDAQ_AD_PROTO_VERSION, PHYSDAQ_FW_STRING, ble_device_name());

    printk("%s", line);
    ble_send((const uint8_t *)line, n);

    n = snprintk(line, sizeof(line),
        "Boot: cause=0x%x (%s), up %lld s\n",
        (unsigned int)boot_cause, boot_cause_str(boot_cause),
        (long long)((k_uptime_get() - boot_ms) / 1000));
    printk("%s", line);
    ble_send((const uint8_t *)line, n);

    n = crashlog_format(line, sizeof(line));
    if (n > 0) {
        printk("%s", line);
        ble_send((const uint8_t *)line, n);
    }
    n = crashlog_format_hang(line, sizeof(line));
    if (n > 0) {
        printk("%s", line);
        ble_send((const uint8_t *)line, n);
    }
}

int main(void)
{
    boot_ms = k_uptime_get();
    crashlog_init();
    if (hwinfo_get_reset_cause(&boot_cause) == 0) {
        /* Cleared so the next boot reports its own cause, not this one. */
        hwinfo_clear_reset_cause();
    }

    if (imu_init() < 0) {
        return 0;
    }

    if (max30102_init() < 0) {
        printk("MAX30102 init failed — halting\n");
        return 0;
    }

    if (battery_init() < 0) {
        printk("Battery ADC init failed — continuing without battery status\n");
    }

    contact_init();
    power_init();

    if (ble_init() < 0) {
        printk("BLE init failed — running USB-only\n");
    }

    /* Arm the watchdog only after all (potentially slow) init has finished,
     * so init delays can never trip it. From here on, main() must feed it. */
    watchdog_init();

    printk("\n=== PhysDAQ: PPG + IMU acquisition ===\n");
    printk("PPG: SpO2 mode, 100 Hz, 18-bit ADC\n");
    printk("IMU: accel [m/s^2], gyro [rad/s]\n");
    printk("BLE: NUS advertising as PhysDAQ\n");
    printk("Battery: VBAT via P0.31/AIN7, sampled every 5 s\n");
    printk("Power: sleep after %d s idle\n\n",
           CONFIG_PHYSDAQ_IDLE_TIMEOUT_SEC);

    send_identity();

    int64_t last_data_ms = k_uptime_get();

    while (1) {
        /* Feed the watchdog once per outer iteration. The loop turns over at
         * least every 200 ms (the max30102_wait_ready timeout), so if anything
         * below hangs — a wedged I2C transfer in particular — the feeds stop
         * and the SoC resets itself within the WDT window instead of freezing
         * indefinitely. */
        watchdog_feed();

        /* Rising edge of a host link, on either transport. BLE: keyed on the
         * *subscription*, not the connection — on the connection edge the
         * central has not enabled notifications yet and ble_send() drops the
         * line. USB: keyed on DTR — the console does not exist while the
         * board boots, so the boot copy is routinely lost there, and this is
         * what makes the ID and Boot lines show up in `make term`. */
        static bool was_linked;
        watchdog_set_stage("identity");
        bool linked = ble_is_subscribed() || power_usb_host_open();
        if (linked && !was_linked) {
            send_identity();
        }
        was_linked = linked;
        watchdog_set_stage("diagnostics");
        ble_flush_diagnostics();

        /* Wait for a PPG_RDY interrupt, or fall through on the timeout. The
         * timeout path is harmless and self-healing: max30102_wait_ready()
         * clears the interrupt flag on every wake, and max30102_fetch() polls
         * the FIFO (returning -ENODATA when empty), so a missed edge costs one
         * timeout of latency rather than a permanent stall. */
        watchdog_set_stage("wait_ready");
        max30102_wait_ready(K_MSEC(200));

        struct ppg_sample ppg;
        struct imu_sample imu;
        bool got_data = false;

        watchdog_set_stage("ppg_fetch");
        while (max30102_fetch(&ppg) == 0) {
            /* Fed here as well as at the top of the outer loop. This inner
             * loop only exits once the FIFO is empty, and when one sample's
             * worth of work (I2C reads, a 120 B printk over USB CDC, a BLE
             * notify) takes longer than the 10 ms sample period the FIFO
             * never empties — the loop spins healthily forever, the outer
             * feed is never reached, and the watchdog resets a node that was
             * streaming perfectly, with no message on either transport. That
             * was the "silent drop mid-stream" signature. A hang inside this
             * loop (wedged I2C) still stops the feeds, so the guard holds. */
            watchdog_feed();
            got_data = true;
            watchdog_set_stage("imu_fetch");
            if (imu_fetch_sample(&imu) < 0) {
                watchdog_set_stage("ppg_fetch");
                continue;
            }
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

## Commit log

2026-06-04 chore: scaffold OS-agnostic Zephyr repo for MAID firmware
    - Add west.yml pinning Zephyr v3.6.0
    - Add firmware/ with CMakeLists, prj.conf, board overlay, and main.c
    - Add cross-platform scripts (build-wrapper, uf2-flash, term, setup-env)
    - Add Makefile exposing build / flash / term / clean / setup targets
    - Add .gitignore, .gitattributes, README, and SETUP docs
2026-06-04 feat: add IMU sensor, RGB LED control, and live gyro plotter (#2)
    - Enable LSM6DSL driver (CONFIG_I2C/SENSOR/LSM6DSL) and set ODR to 104 Hz
    - Split firmware into modules: led.c handles RGB GPIO, imu.c handles fetch/print
    - RGB LED control via UART commands (r/g/b/w/0)
    - Fix float printing by using sensor_value val1/val2 directly
    - Add scripts/plotter.py: real-time pyqtgraph gyro visualization (make plot)
    [led.c, main.c, plotter.py]
2026-06-04 feat: add 3D orientation visualizer via Madgwick filter (imufusion) (#3)
    - Rewrite scripts/plotter.py: left panel = gyro time series, right panel =
    3D board mesh rotating in real time using Madgwick AHRS (imufusion)
    - Parse accel + gyro; feed AHRS with actual dt; apply quaternion as rotation
    matrix via QMatrix4x4 + setTransform (replaces brittle Euler + rotate())
    - Auto-detect imufusion update method name (API changed across versions)
    - Body-frame axes rotate with the board; world-frame axes stay fixed
    - Bump firmware sample rate 500ms -> 50ms (20 Hz) for smooth animation
    - Makefile: auto-detect .venv via Make wildcard (cross-platform, no shell);
    all targets use $(PYTHON); .venv/ added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
    [main.c, plotter.py]
2026-06-04 fix: ZUPT drift correction, serial reconnect, and env isolation (#4)
    - plotter.py: add ZUPT (Zero Velocity Update) — when gyro norm < 0.05 rad/s
    for 10 consecutive samples, pass zero gyro to Madgwick to freeze yaw drift;
    logs "ZUPT: ON/OFF" transitions to console
    - plotter.py: serial reconnect — after 5 consecutive read errors (e.g. Windows
    CDC ClearCommError) close and reopen the port automatically; first error is
    logged once instead of spamming
    - Makefile: prepend PYTHONPATH= to term/plot targets so the Nordic toolchain's
    PYTHONPATH does not shadow venv packages (numpy version conflict)
    - build-wrapper.py: check for west in PATH before invoking and print actionable
    error wi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
    [build-wrapper.py, plotter.py]
2026-06-04 feat: add die temperature reading with ambient estimation (#5)
    - imu.c: read SENSOR_CHAN_DIE_TEMP after accel/gyro and append to serial
    output as " | T:XX.XXX"
    - plotter.py: extend PATTERN regex to optionally capture T field (backward
    compatible with older firmware builds)
    - plotter.py: add TEMP_SELF_HEATING offset constant (default 12.0°C) with
    calibration instructions in comments
    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
2026-06-15 feat: MAX30102 PPG integration and offline analysis pipeline (#6) (#6)
    * feat: add MAX30102 PPG driver and combined PPG+IMU firmware output (#6)
    - Custom interrupt-driven MAX30102 driver (firmware/src/max30102.c/.h)
    SpO2 mode, 100 Hz, 18-bit ADC, PPG_RDY interrupt on D1/P0.03
    - DTS binding (firmware/dts/bindings/sensor/maxim,max30102.yaml)
    - Overlay: MAX30102 on i2c1 @ 0x57, INT on gpio0 pin 3 with pull-up,
    clock reduced to 100 kHz for reliable operation on external bus
    - main.c: PPG+IMU acquisition loop driven by PPG_RDY interrupt
    output format: PPG red=<18bit> ir=<18bit> | IMU ax=... gz=...
    - imu.c/h: expose imu_fetch_sample() for use from main loop
    - CLAUDE.md: hardware reference f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
    [build-wrapper.py, logger.py, main.c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]
2026-06-15 feat: add interactive data explorer and fix Euler angles in pipeline (#7)
    - analysis/explore.py: pyqtgraph viewer for logged CSV data
    all panels linked on time axis (pan/zoom syncs together)
    auto-detects enriched + beats counterparts from any CSV in the set
    panels: PPG raw, PPG filtered + beat markers, BPM/RMSSD scatter,
    gyro, Madgwick orientation, dynamic accel + motion shading
    make explore FILE=logs/....csv
    - analysis/pipeline.py: fix Euler angles computation from quaternion
    (ahrs.euler attribute absent in installed imufusion version)
    - Makefile: add make explore target
    [explore.py, pipeline.py]
2026-06-15 feat: motion-based deep sleep with configurable idle timeout (#8)
    - Enters nRF System Off (~0.4 µA) after N seconds of gyro inactivity
    - IMU reconfigured at sleep for wake-up detection on INT1 (P0.11);
    device fully reboots on motion — no partial-resume complexity
    - MAX30102 set to SHDN before sleep (~0.7 µA, I2C kept alive)
    - Timeout configurable via CONFIG_MAID_IDLE_TIMEOUT_SEC in prj.conf
    (default 30 s, range 5–300 s), no source change needed
    - Serial prints idle countdown every 5 s so threshold is observable
    - I2C bus recovery + retry on MAX30102 init to survive post-sleep glitch
    - Fix CLAUDE.md: gyro unit was documented as dps, is rad/s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
    [main.c, max30102.c, power.c]
2026-06-15 feat: BLE NUS wireless streaming (#9)
    Firmware:
    - Add BLE NUS peripheral (firmware/src/ble.c) — same data format as USB
    - Advertise by NUS service UUID so PC can discover without knowing address
    - USB serial + BLE NUS both active simultaneously; BLE stops on deep sleep
    and resumes advertising on wake (full reboot)
    PC:
    - scripts/ble-reader.py: standalone BLE NUS receiver, streams to stdout
    - analysis/logger.py: --ble flag routes input from BLE instead of serial
    - scripts/plotter.py: --ble flag swaps serial thread for BLE thread
    - Makefile: make ble-log, make ble-plot targets
    Dependency: pip install bleak (already in .venv)
    [ble-reader.py, logger.py, main.c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]
2026-06-15 fix: BLE MTU fragmentation and multi-device UUID discovery (#10)
    - Negotiate larger ATT MTU (up to 244 B payload) on connect so full
    data lines (~120 B) fit in one notify instead of being silently dropped
    - Fragment ble_send() into MTU-sized chunks for robustness
    - Add CONFIG_BT_L2CAP_TX_MTU=247 and ACL buffer sizes to prj.conf
    - Discovery by NUS service UUID (not device name) in ble-reader.py,
    logger.py, plotter.py — multi-patient safe
    - Interactive device picker when multiple sensors in range
    - --ble-addr=<addr> flag to skip discovery and target directly
    - Makefile ADDR= variable: make ble-log ADDR=DA:10:... / make ble-plot ADDR=...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
    [ble-reader.py, logger.py, plotter.py]
2026-06-15 fix: BLE auto-reconnect on disconnect or data timeout
    All three BLE tools (plotter, logger, ble-reader) now loop on
    disconnect instead of silently freezing the UI or stopping output.
    Plotter also includes a 10s no-data watchdog that forces a reconnect
    cycle in case notifications stop arriving without a clean disconnect.
    [ble-reader.py, logger.py, plotter.py]
2026-06-15 fix: add CONFIG_BT_GATT_CLIENT=y to link bt_gatt_exchange_mtu
    bt_gatt_exchange_mtu() lives in the GATT client subsystem — without
    this Kconfig the linker raises an undefined reference even though
    the board is configured as a peripheral.
2026-06-15 fix: reset BLE watchdog after subscribe, not at script start
    last_data was initialized at ble_reader() entry. BLE scan (~8s) +
    connect + MTU exchange (~2s) = watchdog already expired before the
    first notification, causing immediate disconnect on every attempt.
    Now reset last_data[0] right after start_notify() so the 10s window
    starts counting from when the subscription is live.
    [plotter.py]
2026-06-15 fix: BLE scan retries forever instead of exiting on no device found
    Previously the scanner called sys.exit() when no device was found,
    requiring manual restart whenever the board was sleeping. Now it loops
    every 5s with a clear message ("move it to wake"), plus a fallback
    unfiltered scan for Windows WinRT compat (service_uuids filter
    can miss devices depending on the WinRT advertisement cache).
    [ble-reader.py, logger.py, plotter.py]
2026-06-15 fix: BLE TX congestion and deep sleep with BLE active
    Two root causes fixed:
    1. BLE congestion (no data visible on PC):
    100 Hz × 120 B/sample = 12 kB/s exceeds BLE link capacity (~4 kB/s
    at default Windows connection interval). bt_gatt_notify() was silently
    returning -ENOMEM and dropping all samples.
    Fix: cap BLE sends at 25 Hz (one per 40 ms) in main.c; bail early in
    ble_send() on first notify error instead of spinning through all chunks.
    2. Deep sleep broken when BLE is active:
    nrf_power_system_off() can be ignored/hang if the nRF BLE controller
    still has pending connection or advertising work.
    Fix: ble_stop() disconnects any active connection, stops advertising,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
    [main.c, power.c]
2026-06-15 feat: motion artifact removal and spectral BPM estimation
    pipeline.py:
    - motion_cancel(): Wiener-optimal regression — bandpass-filtered accel
    (3 axes × 8 delay taps) projected out of PPG via least-squares.
    Faster than sample-by-sample LMS; matches quality for stationary
    motion characteristics typical of wrist/finger PPG.
    - spectral_bpm(): sliding 8-s FFT window, suppresses bins where
    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
2026-06-15 feat: widen PPG bandpass to 8 Hz and add dedicated filtered plot
    Root cause of flat sinusoidal appearance: 4 Hz cutoff passed only the
    fundamental + one harmonic. At 70 BPM (1.17 Hz), the 3rd harmonic is
    3.5 Hz, 4th is 4.7 Hz — both lost. The result looked like a pure sine.
    Changes:
    - PPG_HIGH_HZ: 4.0 → 8.0 Hz (preserves 6+ cardiac harmonics, giving
    proper systolic peak + dicrotic notch shape)
    - MOTION_HIGH_HZ: 3.5 Hz (separate cap for accel reference in
    motion_cancel — avoids regressing out cardiac harmonics from PPG)
    - plotter: dedicated "PPG filtré" sub-plot with its own y-axis so the
    AC signal fills the space instead of being crushed by DC amplitude;
    BPM shown in plot tit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
    [pipeline.py, plotter.py]
2026-06-16 feat: add battery percentage status via VBAT ADC
    Reads VBAT through the onboard 1M/510k divider on AIN7 (P0.31), gated
    by the P0.14 read-enable pin to avoid the increased sleep-current
    issue reported for this circuit. Maps voltage to state-of-charge with
    a single-cell LiPo discharge curve and reports it every 5 s over USB
    console and BLE NUS, alongside the existing PPG/IMU stream.
    [battery.c, main.c]
2026-06-16 fix: stabilize PPG BPM estimation and document battery status
    The 8 Hz-wide display bandpass (needed for proper pulse shape) was also
    being fed straight into beat detection and the live FFT estimator,
    where its harmonics/dicrotic notch caused either missed beats (global
    prominence threshold too strict — one log produced 1 beat in 33 s) or
    locked-on harmonic frequencies. Root-caused against logs/2026-06-15_11-16-25.csv.
    analysis/pipeline.py:
    - compute_beats() now picks peaks on a narrowband (0.7-3.0 Hz,
    fundamental-only) signal instead of the wide display band, with an
    adaptive rolling-RMS height threshold and an IBI-outlier median gate.
    - spectral_bpm() now skips windows without a cle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
    [explore.py, pipeline.py, plotter.py]
2026-06-16 feat: detect skin contact, stop reporting BPM with nothing on the sensor
    The MAX30102 IR photodiode has a near-baseline DC level in open air
    (only ambient light) and a much higher one with skin backscattering
    the LED — measured on this hardware as ~100-300 counts vs ~29000+
    (see CONTACT_IR_MIN comment in analysis/pipeline.py for the basis and
    how to recalibrate if LED current/gain changes). Without this gate the
    existing filters/FFT could still report a plausible-looking BPM from
    ambient noise alone.
    - compute_contact() flags samples below the IR DC threshold; both
    compute_beats() and spectral_bpm() now drop data from those periods
    instead of treating it as a nor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
    [explore.py, pipeline.py, plotter.py]
2026-06-16 feat: combine validated skin contact with motion in the sleep decision
    Sleep used to trigger purely on gyro inactivity, so sitting still while
    worn (e.g. resting) would put the device to sleep same as setting it
    down. Now sleep requires both no motion AND no validated skin contact.
    firmware/src/contact.c (new): tracks the IR DC level (same threshold as
    analysis/pipeline.py's CONTACT_IR_MIN) to detect something on the
    sensor, then requires a few consecutive peak-to-peak intervals in the
    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
2026-06-16 docs: update CLAUDE.md with sleep behavior and contact validation details
    Also refine contact validation and power management documentation to reflect
    the combined skin-contact and motion-based sleep decision logic.
2026-06-16 feat: add robust serial port/BLE auto-reconnection and interactive device lists
2026-06-16 style: remove gradient text and buttons, use vanilla shadcn dialog disconnect popup
2026-06-16 feat(app): improve body skeleton wireframe, add finger sensor support, interactive timeline range zooming, and responsive UI layout
2026-06-16 feat(app): add interactive timeline scrubber track with sparkline and zoom/pan navigator controls
2026-06-16 feat(app): replace emojis with Lucide icons, implement time format ruler markings, and fix blank ppg_filt graph with a robust pure-python EMA filter and JS fallback
    [bridge.py]
2026-07-02 fix: repair PPG acquisition, BLE-by-address on Windows, and venv Python env
    - max30102: clear INT_STATUS1 and prime the semaphore after arming the
    falling-edge interrupt. The sensor streams at 100 Hz during the >200 ms
    init, so INT was already asserted LOW by the time the trigger was armed;
    with no further falling edge the acquisition thread blocked forever in
    wait_ready() — no PPG samples, no BLE output, device never slept.
    - bridge.py: always resolve a BLEDevice via a scan before connecting, in
    both the --ble and --ble-addr paths. On Windows (WinRT) BleakClient
    cannot connect to a bare address that wasn't discovered in the same
    process, so connecting by address (the app's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
    [bridge.py, max30102.c]
2026-07-02 fix: stop acquisition stalls that froze the UI, plus firmware/app hardening
    The "UI freeze after a while" was traced (via a temporary heap/render/sample
    probe) to the device silently stopping data, not the renderer — heap and
    frame rate stayed healthy while incoming samples dropped to zero. Root cause
    was in the sensor path:
    - max30102: enable FIFO rollover (FIFO_CFG 0x00 -> 0x10). With rollover off,
    once the 32-deep FIFO fills the sensor stops writing and the write pointer
    freezes, so max30102_fetch() sees an empty FIFO forever and every downstream
    consumer (serial, BLE, power mgmt) freezes while the CPU keeps running.
    - main: recover from a sensor/I2C stall by re-initialising the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
    [bridge.py, main.c, max30102.c]
2026-08-10 feat: adopt the PhysDAQ mark and rewrite the README for researchers
    The README was 143 lines of developer-first text whose quick start opened with
    `make setup` and a venv, but the audience is researchers who need to know how to
    record a participant, not how to compile firmware. Rewrite it at 103 lines with
    a researcher-first quick start, plain-language feature bullets, and a
    documentation table keyed on intent rather than document titles. The ASCII
    architecture diagram and the no-mesh scope note move to docs/protocol.md, which
    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
2026-08-10 ci: build releases for Windows, macOS and Linux on tag
    The README now points researchers at the Releases page, but nothing could fill
    it: there was no CI, no tags and no publish config. PyInstaller does not
    cross-compile, so shipping three platforms from one machine is impossible --
    app/sidecar/bridge/ is a single unnamespaced slot, and `npm run build:linux` on
    Windows would silently copy bridge.exe into an AppImage that dies at launch with
    "Python sidecar not found".
    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
2026-08-10 docs: state that only the Windows build is published
    The Mac and Linux legs of the release workflow have never had a successful run,
    so listing their artifacts as if they were downloadable sends researchers to
    files that do not exist.
    Claude-Session: https://claude.ai/code/session_01GgxnPAVqTf7SYWy4LkNMdL
2026-08-10 docs: all four platform builds are published
    The first CI run succeeded on every leg, so the Windows-only caveat added a
    commit ago is already wrong. Mac and Linux artifacts are attached to v1.0.0.
    They are still flagged as unverified: they package cleanly but nobody has
    launched them on real hardware yet, and that is a different claim from "works".
    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
2026-08-10 feat(app): filter the BLE scan to nodes, and make device pickers searchable
    Configuring a node meant reading raw MAC addresses out of an unfiltered list.
    scripts/bridge.py defined NUS_SERVICE_UUID and then never used it, so
    BleakScanner.discover() returned every advertiser in range -- typically dozens,
    most of them "Unknown Device" -- and the handful that were actually ours were
    buried in it.
    Filter the scan on the NUS service UUID, which firmware/src/ble.c already puts
    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
2026-08-10 feat(firmware): give each node a unique advertised name
    Every unit built from this tree advertised the identical string "PhysDAQ" --
    a compile-time literal, sized with sizeof(CONFIG_BT_DEVICE_NAME) - 1 -- so a BLE
    scan could not tell two nodes apart. The MAC address was the only discriminator,
    which is what made picking the right node from a dropdown guesswork.
    Append the last two bytes of the SoC's factory device ID, giving PhysDAQ-XXXX.
    The suffix is derived at boot, not stored: this board has no NVS configured, and
    FICR is stable across reboots and reflashes anyway, so deriving it avoids
    pulling in FLASH/FLASH_MAP/NVS/SETTINGS for a value that never changes.
    sd[] therefore has to be fil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
2026-08-10 feat(app): flash a node from the desktop app
    Setting up a node meant leaving the app entirely: a Zephyr toolchain, make
    flash, and scripts/uf2-flash.py. A researcher was never going to do that.
    CI now builds zephyr.uf2 once and hands it to all three app jobs, which stage it
    at app/resources/firmware/physdaq.uf2 so electron-builder ships it as
    extraResources -- next to the sidecar, outside asar, resolved the same way. The
    image is hardware-specific rather than host-specific, so it is built once rather
    than per-OS, and it is attached to the release for flashing by hand too.
    *.uf2 is gitignored, so a local build bundles nothing and the flash button
    reports itself unavailable rather than crash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
2026-08-10 chore: release v1.1.0
    Node discovery, per-node names and in-app flashing since v1.0.0.
    The lockfile also picks up two pieces of drift: its "name" field still said
    "app" from before the rename, and npm re-materialised the bundled optional
    @tailwindcss/oxide-wasm32-wasi platform packages. No direct dependency versions
    change; `npm ci` and typecheck were run against the result.
    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
2026-08-27 feat: dual-PPG microSD hub, host command channel, app support
    Adds firmware-hub/ — a second Zephyr application for a XIAO nRF52840 Sense
    carrying two MAX30102 sensors behind a PCA9546A mux plus a microSD card — and
    teaches the rest of the stack about it.
    Firmware (firmware-hub/):
    - Two PPG sensors on mux channels 1 and 2, sampled into one wire line
    ("PPG red=… | PPG1 red=… | IMU …") so the pair shares an arrival timestamp
    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
    [physdaq-case-v1.step, physdaq-lid-v1.step]
2026-08-28 fix: stop BLE-linked nodes rebooting mid-session, make crashes visible
    Nodes "kept disconnecting" over BLE. They were not losing the radio: they
    were rebooting, and the boot report added here (Boot: cause=watchdog) is
    what finally showed it. Three stacked defects, in both firmwares:
    - bt_gatt_notify() allocates its PDU with K_FOREVER (Zephyr att.c) and
    blocks indefinitely once the ACL TX buffers are exhausted. Called from
    main(), it starved the watchdog. ble_send() now only queues; a dedicated
    ble_tx thread is the sole caller of the radio. Lines are dropped, never
    blocked on, and the count is shown in the Power: status line.
    - The controller still ran 27 B LL packets while the host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
    [bridge.py, main.c, power.c]

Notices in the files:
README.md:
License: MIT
